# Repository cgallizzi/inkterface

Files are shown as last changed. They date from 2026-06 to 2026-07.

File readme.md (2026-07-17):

inkterface now playing

# Inkterface: Now Playing Edition

An e-ink faceplate for your Steam Machine that shows the box art, playtime,
and achievement progress of whatever you're playing — plus all the original
system telemetry readouts.

Video Project 2

> This is a community fork of
> [Valve's Inkterface](https://gitlab.steamos.cloud/SteamHardware/SteamMachine/inkterface),
> created by NaKyle Wright at Valve and released under the MIT license.
> All of the hardware design, assembly docs, and the original firmware and
> companion app are their work — this fork adds the artwork/"now playing"
> features and easier install tooling on top. Thank you Valve for open
> sourcing it!

## What this fork adds

* **Now Playing artwork mode**: when you launch a game, the panel switches to
  that game's box art with your total playtime and achievement progress
  rendered next to it (dithered for the e-ink look). When you quit, it goes
  back to the regular telemetry layout. Toggle it with the `Box Art` button
  in the configure screen.
* **Game collectors**: `Game Time` and `Achievements` readouts you can put in
  any panel field, alongside the stock CPU/GPU/fan stats.
* **Browser firmware flasher**: flash your Feather from Chrome/Edge at the
  project's GitHub Pages site — no toolchain install needed.
* **One-line app install**: paste a single command on your Steam Machine and
  you're done — no building, no USB sticks.

Achievement data comes from the Steam Community profile endpoint and requires
no API key, but your profile's game details need to be public for it to show.

## Quick Install (this fork)

**Firmware** — plug the Feather into any PC over USB and open the
[web flasher](https://cgallizzi.github.io/inkterface/) in Chrome or Edge, then
click Install for your board.

**App** — on the Steam Machine, open a terminal in desktop mode and run:

```sh
curl -fsSL https://raw.githubusercontent.com/cgallizzi/inkterface/main/scripts/install.sh | sh
```

That downloads the latest release to `~/Applications`, launches it, and from
there you pick your panel and click Install (bottom right) to set up the
background service. Prebuilt AppImages are also on the
[releases page](https://github.com/cgallizzi/inkterface/releases) if you'd rather
grab one manually.

Everything below is the original upstream documentation for building the
hardware and working from source.

## Required Hardware

* 1 x Adafruit ESP32-S3 Feather w/ 2MB PSRAM
    * [Link to V1 Board, as shown in the assembly video and document!](https://www.adafruit.com/product/5477)
    * [Link to V2 Board, accidentally the only link previously!](https://www.adafruit.com/product/5400)
    * Both the V1 and V2 modules work, but they have different pinouts, make sure
      to check if you see the "V2" silkscreen on your board and choose the correct
      pinout sheet and environment when building the firmware!
* 1 x [Adafruit eInk Breakout Friend](https://www.adafruit.com/product/4224)
* 1 x [Adafruit 5.83" Monochrome eInk Panel](https://www.adafruit.com/product/6397)
* 1 x [LP803860 Battery](https://www.adafruit.com/product/2011)
* 13 x M2.5 x 5mm Pan Head Machine Screws
    * [McMaster](https://www.mcmaster.com/92000A103/)
    * [Amazon](https://www.amazon.com/dp/B0GC58C2V5)
* 4 x [1/4" x 1/4" x 3/16" Stepped Magnet SB443-OUT](https://www.kjmagnetics.com/sb443-out-neodymium-stepped-block-magnet)

## Assembly

Check out the assembly tutorial video in
[the upstream repo](https://gitlab.steamos.cloud/SteamHardware/SteamMachine/inkterface/-/blob/main/docs/Inkterface%20Assembly.mp4)
(kept out of this fork because it exceeds GitHub's file size limit),
or if you'd prefer there is a PDF version too `./docs/Inkterface Assembly.pdf`.

**_Warning: The screws will thread themselves into the plastic, but be VERY gentle
as it is easy to strip the plastic away and you may need to re-print parts!_**

1. Print parts from `./cad` folder.
    * Individual parts are included as separate STEP files, but a combined file
      with all parts that is ready for printing on a Stratasys F370 build plate
      is also provided as `Inkterface - Print Plate.step`.
2. Attach the ESP32 Feather and eInk Breakout to the board plate layer using 4x screws.
    * Having them held in place helps with soldering the connections and sizing your wires.
3. Solder wires between the pins of the two boards.
    * MOSI/MISO/SCK/GND all connect directly as expected.
    * 3V3 from the feather connects to VIN on the breakout.
        * The 3V3 pin on the breakout is a 3V3 output.
    * For the **_V1_** feather connect these pins, like Feather -> Breakout:
        * PIN 6 -> ENA
        * PIN 9 -> BUSY
        * PIN 10 -> RST
        * PIN 11 -> SRCS
        * PIN 12 -> D/C
        * PIN 13 -> ECS
    * For the **_V2_** feather connect these pins, like Feather -> Breakout:
        * PIN 32 -> ENA
        * PIN 15 -> BUSY
        * PIN 33 -> RST
        * PIN 27 -> SRCS
        * PIN 12 -> D/C
        * PIN 13 -> ECS
    * **_NOTE:_** On both feather versions we connect to pins in the same physical
        positions, but they are different logical pins in the firmware.
4. Place the e-ink panel into the matching recess in the faceplate part.
5. Fit the two midplates in.
6. Place the 4 magnets into the recesses in each corner of of the midplates.
    * Magnetic field orientation doesn't matter, they connect to metal slugs
      in the Steam Machine chassis.
7. Place the board plate over the midplates, aligning the magnets and screw holes.
8. Fasten the boardplate with 8x screws in the screw holes along the edges.
9. Connect the e-ink panel to the breakout board.
    * Be careful when handling the flex that comes out of the panel, it is fragile
      and should not be bent or folded.
10. Place the battery in the recess, tucking its wire under the board plate and
    up into the clearance hole beside the feather.
11. Insert and fasten down the battery retainer/cover.
12. Plug the battery connecor into the feather.

Once you've assembled the unit it should be fairly solid and easily magnet to the
front of a Steam Machine!

You will need to build/flash the firmware onto the feather using the steps below.

## Usage

[Eventually we'll have an app up on Steam](https://store.steampowered.com/app/1222770)
but until then you can build an AppImage using the instructions further down in
this readme.

Once you have it built, take a look at `./docs/Inkterface Setup.pdf`, but the
basics are:
1. Enable bluetooth.
2. In desktop mode register as an app in Steam.
    * Or you can just run it directly.
3. Wait for it to discover your panel.
    * If it doesn't appear try clicking the reset button on the back and checking
      that bluetooth is enabled.
4. Select your panel, the name shown should match what's displayed on the inkterface.
    * They all start with an `INKTF-` prefix and then use a unique portion of the
      panels BLE MAC address.
5. On the configure screen, install the service using the button at the bottom
   right.
    * This will set itself up as a user service, so don't move the AppImage or
      that will break, no biggie though, you'll just need to re-run it.
    * Once the service is installed it might take 10-20 seconds for it to connect
      to the inkterface, that's fine, it just needs to go through discovery.
6. Finally you can click any of the readouts to adjust what they display.
    * We have several stats built in, but if you check out `include/panel-state.hpp`
      you can add any function that can return a `QString` or `double` and then
      `registerCollector()` to have it show up in the list.
      * There are some examples of stateful and idempotent collectors in `SysStats`,
        they get registered in the `PanelState` constructor.
7. Exit the configuration app.
    * The service is lightweight and runs in the background, you only need to
      run the config software to select a panel or to change what it displays.

## Building Interface

If you have Qt installed you should be able to open the cmake project in Qt Creator
and use that.

For better distributable builds you can setup a container for wider platform
support using the included `Containerfile`.

1. `podman build -t qt69-builder -f ./Containerfile`
2. `distrobox create --image qt69-builder --name qt69`
3. `distrobox enter qt69`
4. `./scripts/build.sh deploy`

That should produce an AppImage for you in the `./dist-linux-x86_64` folder.

This container uses an older version of Ubuntu and Qt 6.9 which should let us
build AppImages that will work on a wide range of modern systems.

## Building Firmware

For a mix of convenience and approachability this project uses
[PlatformIO](https://platformio.org), and in particular here you'll use the
[pio run](https://docs.platformio.org/en/latest/core/userguide/cmd_run.html)
command. Reading up on them can be useful, especial options like `--upload-port`
which could help if you have multiple serial ports.

If you're using the container from above you can just do:

1. `distrobox enter qt69`
2. `cd ./firmware`
3. If you have a **_V1_** feather: `pio run -e featherv1 -t upload`
4. If you have a **_V2_** feather: `pio run -e featherv2 -t upload`

And it should build and flash the firmware, if you want to get setup manually:

1. Install [PlatformIO](https://platformio.org) for your system.
2. `cd ./firmware`
3. If you have a **_V1_** feather: `pio run -e featherv1 -t upload`
4. If you have a **_V2_** feather: `pio run -e featherv2 -t upload`

Of course in both cases you need to have the ESP32 Feather attached via USB and
permission to interact with serial devices on your system.

**_NOTE:_** You can add build definitions and support for other boards by modifying
the `platformio.ini`, check it out to see the V1 and V2 feather environments.

## Design Docs

Planning out the UI and panel design is done in a Lunacy document you can find
in the `./design` folder.

Lunacy is an open source alternative to tools like Figma that can work entirely
offline.

## License

This project is licensed under the MIT License, see LICENSE.

This project depends on third-party software that is distributed under its own
licenses. Those licenses remain applicable to the respective components and
are not modified by this project's license.

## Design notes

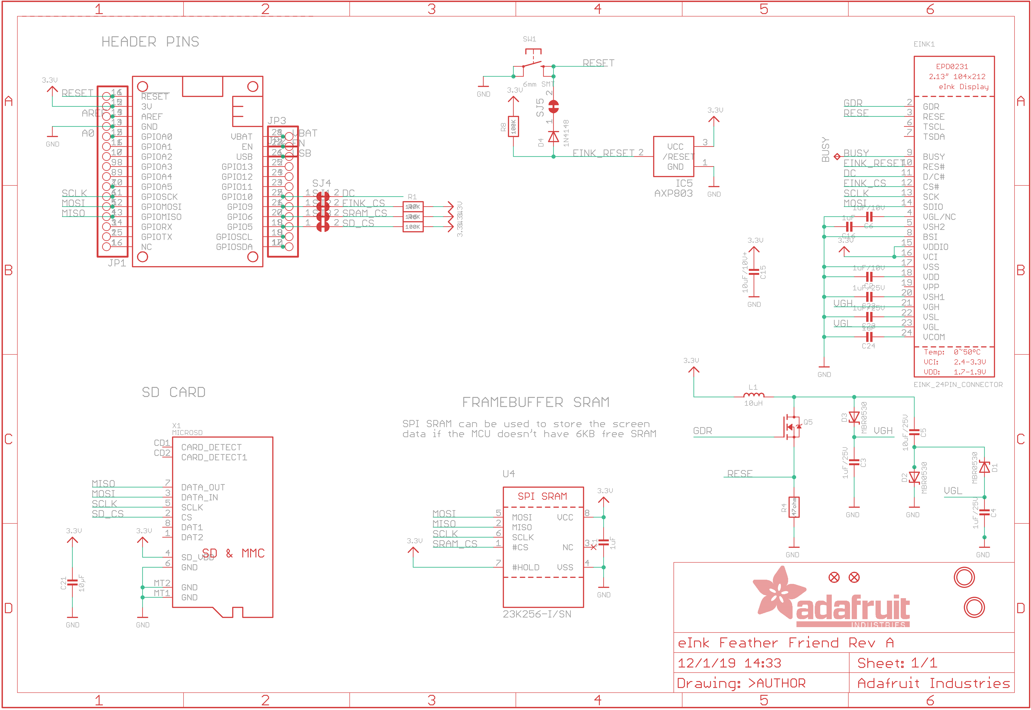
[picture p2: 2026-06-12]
docs/eInk Feather Friend Schematic.png

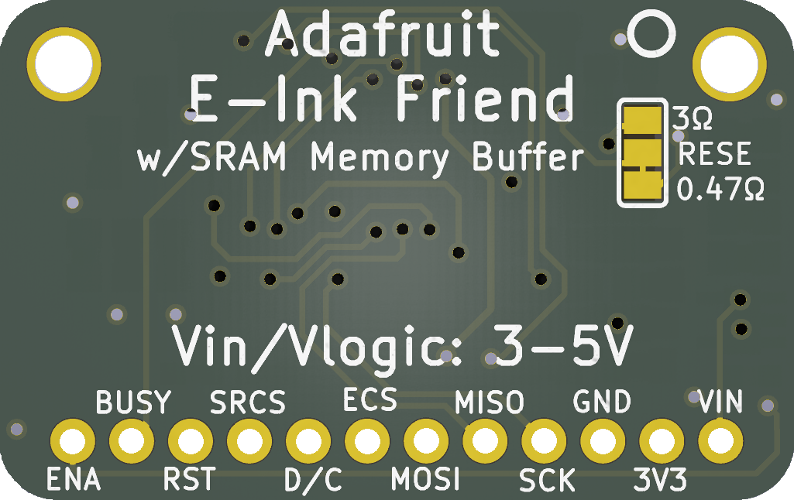
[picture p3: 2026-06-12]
design/breakout-board.png

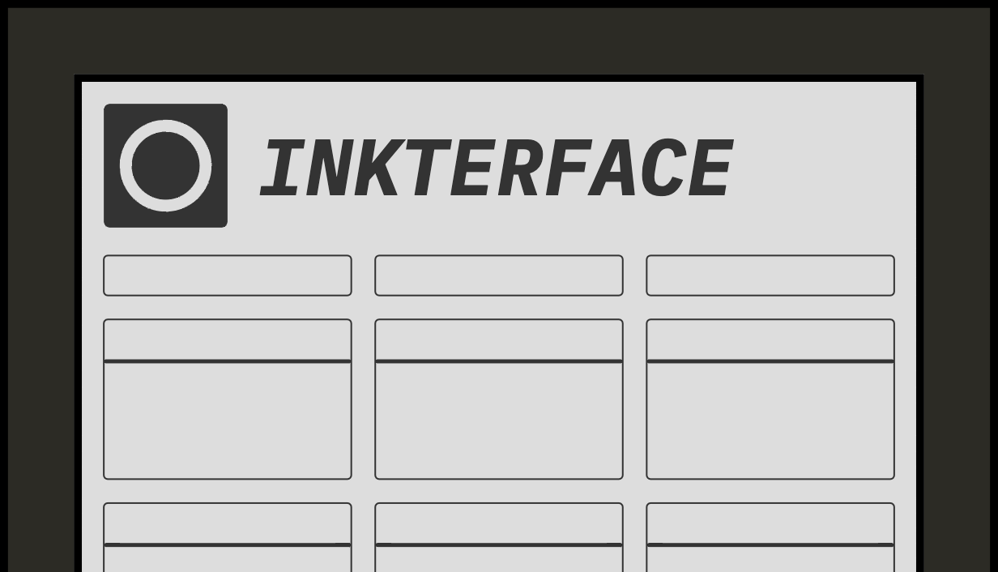
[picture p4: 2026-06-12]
design/store-assets/Main_Capsule.png

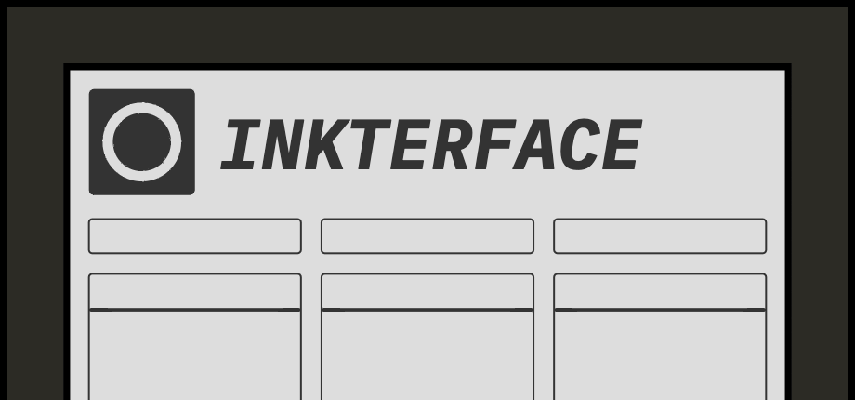
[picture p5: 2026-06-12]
design/store-assets/Library_Header.png

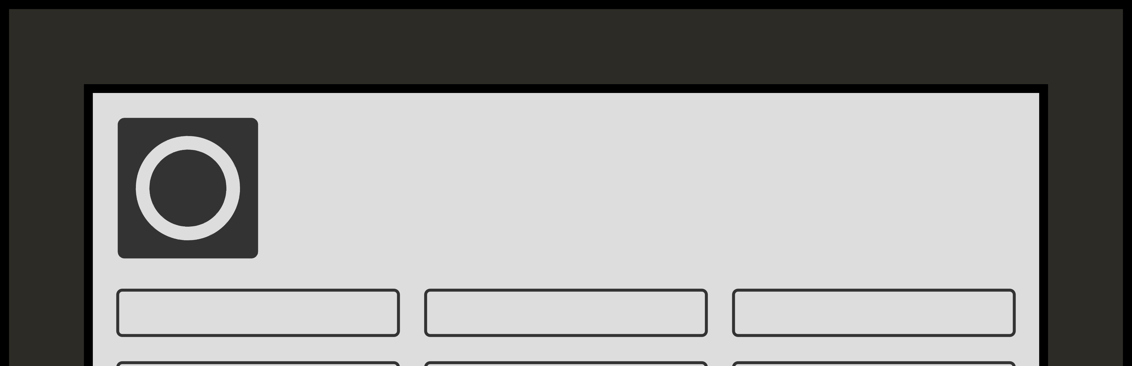
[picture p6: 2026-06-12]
design/store-assets/Library_Hero.png

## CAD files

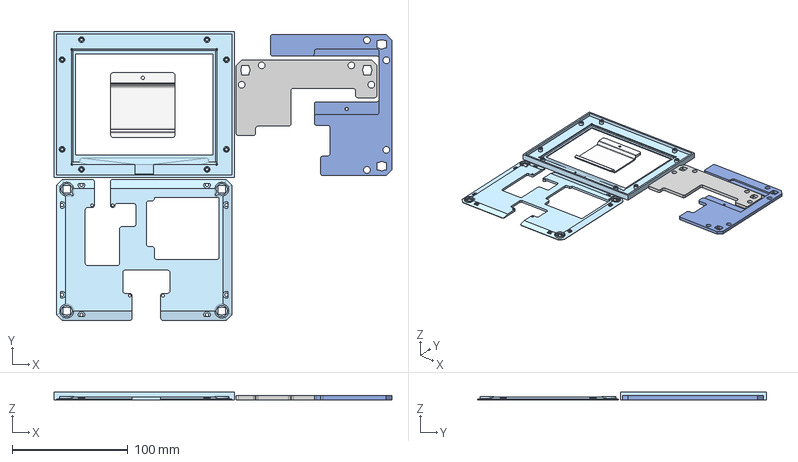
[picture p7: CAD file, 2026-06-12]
cad/Inkterface - Print Plate.step
292.1 x 249.6 x 6.50 mm
Faceplate
Battery Retainer
Board Plate
Midplate Left
Midplate Right

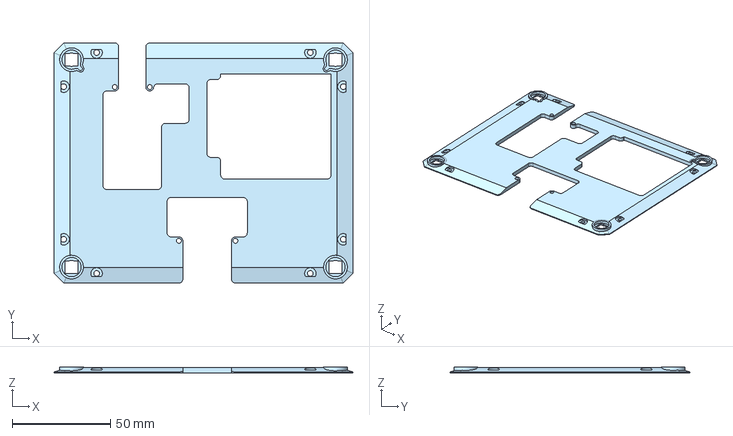
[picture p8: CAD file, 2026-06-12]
cad/Inkterface - Board Plate.step
151.8 x 121.9 x 2.81 mm

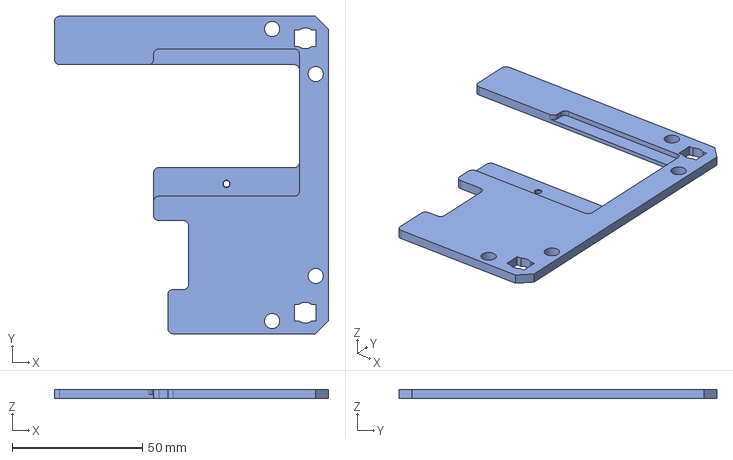
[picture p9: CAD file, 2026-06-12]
cad/Inkterface - Midplate Left.step
105.2 x 121.9 x 3.56 mm

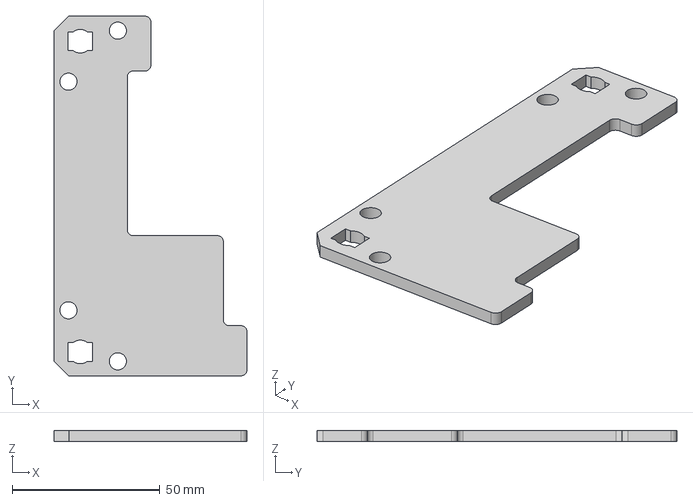
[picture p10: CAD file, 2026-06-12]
cad/Inkterface - Midplate Right.step
65.4 x 121.9 x 3.56 mm

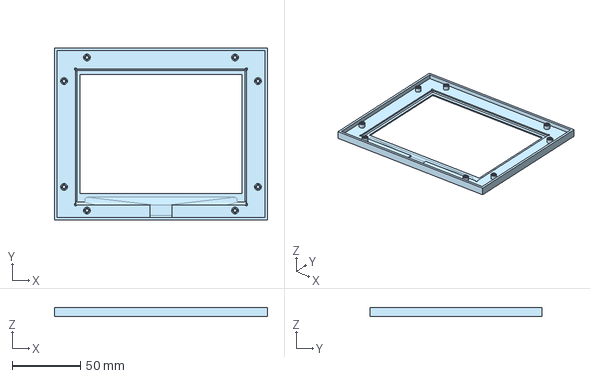
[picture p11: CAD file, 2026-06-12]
cad/Inkterface - Faceplate.step
156.0 x 126.1 x 6.50 mm

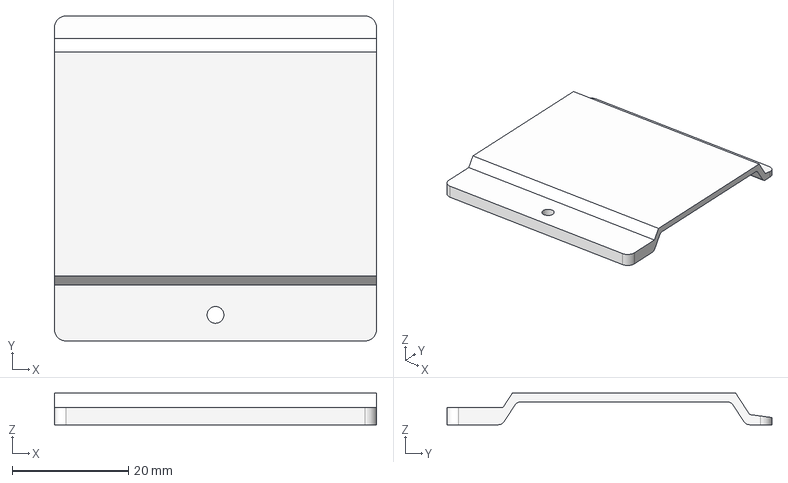
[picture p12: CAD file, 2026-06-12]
cad/Inkterface - Battery Retainer.step
55.5 x 56.0 x 5.44 mm

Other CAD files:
cad/Inkterface - Battery Retainer.stl
cad/Inkterface - Board Plate.stl
cad/Inkterface - Faceplate.stl
cad/Inkterface - Midplate Left.stl
cad/Inkterface - Midplate Right.stl
cad/Inkterface - Print Plate.stl

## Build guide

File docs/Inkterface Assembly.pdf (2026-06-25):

### Inkterface Assembly (p. 1/2)

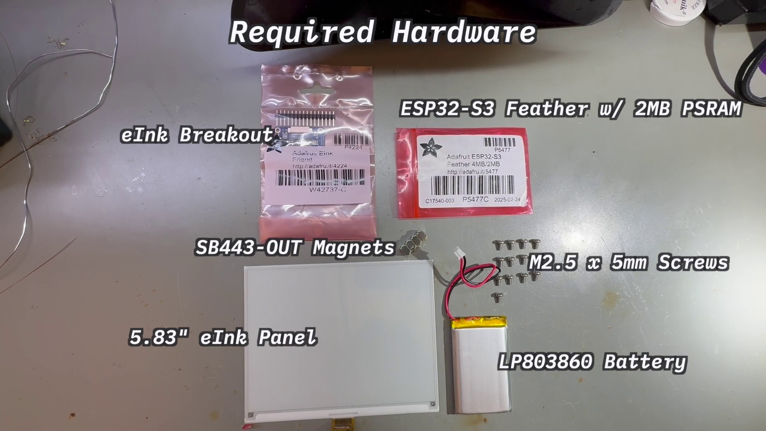
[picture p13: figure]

Collect hardware:
> 1x 5.83" eInk Panel
> 1x Adafruit eInk Breakout
> 1x ESP32-S3 Feather w/ 2MB PSRAM > 1x LP803860 Battery
> 4x K&J Magnetics SB443-OUT Magnets > 13x M2.6 x 5mm Machine Screws

See project readme for links.

Print plastic parts:
> 1x Faceplate
> 1x Battery Retainer
> 1x Right Midplate
> 1x Left Midplate
> 1x Board Plate

There are STEP and STL files provided in the CAD folder of the project.

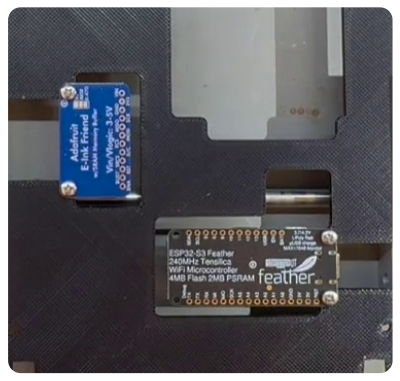
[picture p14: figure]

Attach boards to board plate:

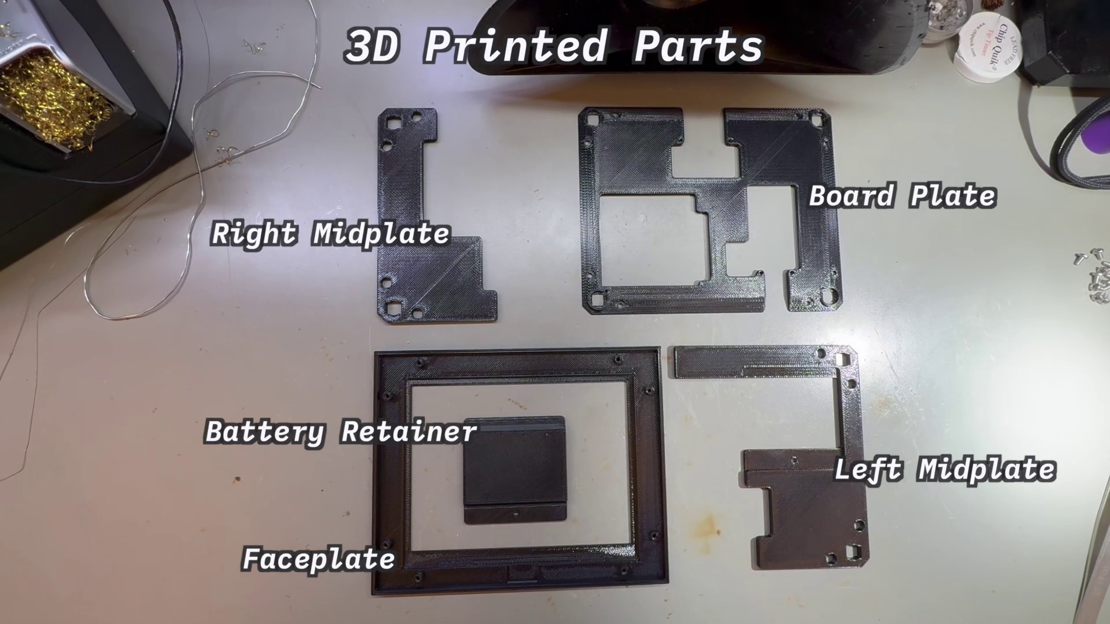
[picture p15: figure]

Use 4 M2.5 x 5mm screws, the breakout and feather.

The boards should lay on the flat side, with the connectors and components facing down.

Mounting them like this makes wiring and soldering easier. Tighten screws gently to avoid damaging the plastic!

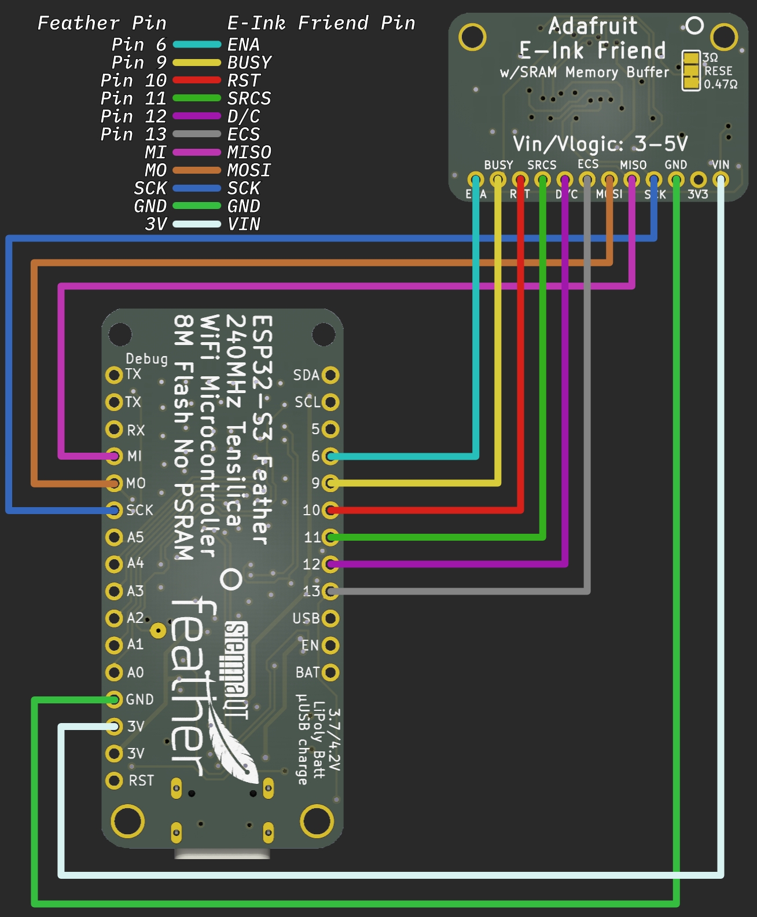
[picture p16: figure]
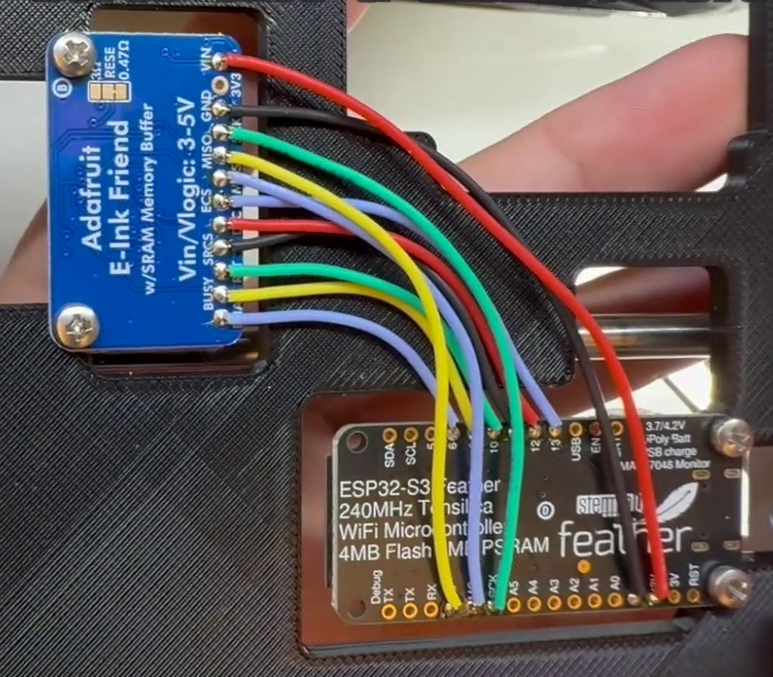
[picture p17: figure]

Wire boards together:
Solder fine gauge wire connections between the boards according to the wiring diagram.

I prefer ~30AWG stranded wire with silicone insulation, but just try to keep the wires as short and direct as possible.

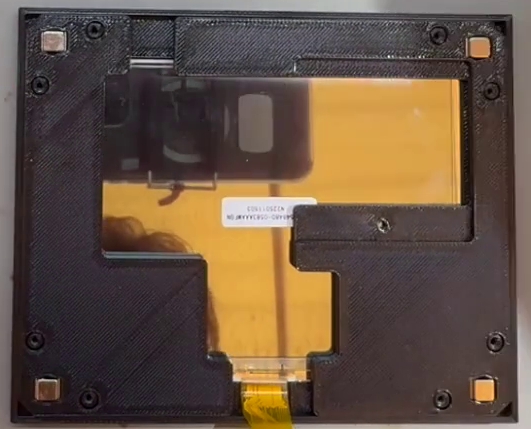
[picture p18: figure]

Assemble faceplate and midplates:
Remove protective film from eInk panel. Place panel in matching recess in faceplate. Place midplates down as seen in image. Install 4 K&J SB443-OUT magnets.
1 in each corner, you may need to press them in forcefully depending on your printer.
p. 1/2

### Inkterface Assembly (p. 2/2)

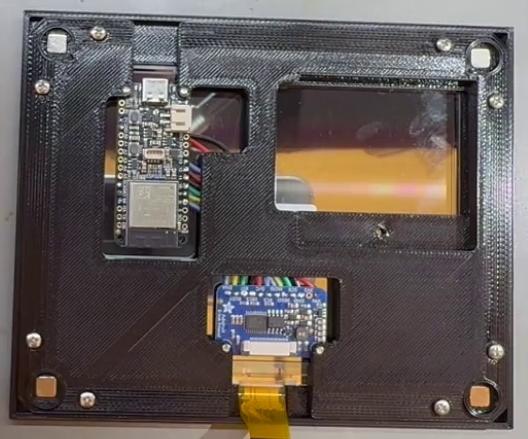
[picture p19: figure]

Mount board plate over midplates:
Carefully position wires so that they fit into the channel between the midplates.

Use 8 M2.5 x 5mm screws, gently tightened to avoid damaging the plastic.

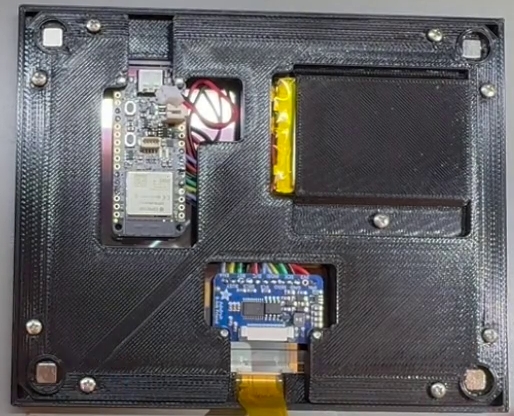
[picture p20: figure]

Mount battery and battery retainer:
Feed battery cable under board plate and up next to the battery connector on the feather.

Place the battery retainer over the battery and fix it in place with 1 M2.5 x 5mm screw.

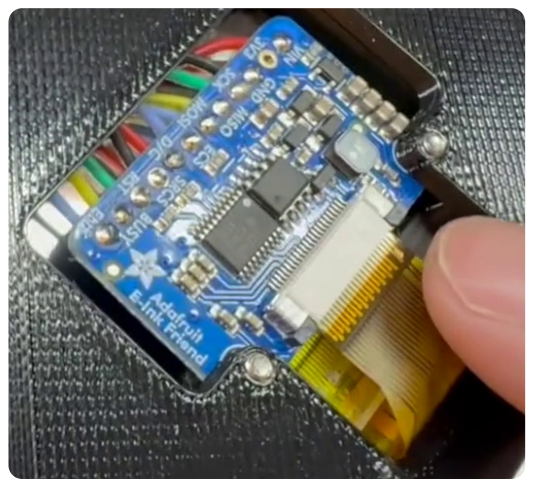
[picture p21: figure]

Connect flex cable to breakout:
Carefully unlatch the connector and feed the flex cable into it.

The cable should seat as shown in the image.

Carefully latch the connector.

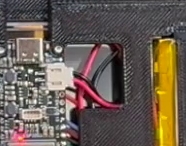
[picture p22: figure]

Connect the battery to the feather:
Connect the battery to the feather.

You should see a red light, this indicates that the board has power.

Assembly Complete!
The next step is to flash the firmware, please see the readme for instructions on setup, building, and flashing!
p. 2/2

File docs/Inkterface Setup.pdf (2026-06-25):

### Inkterface Setup

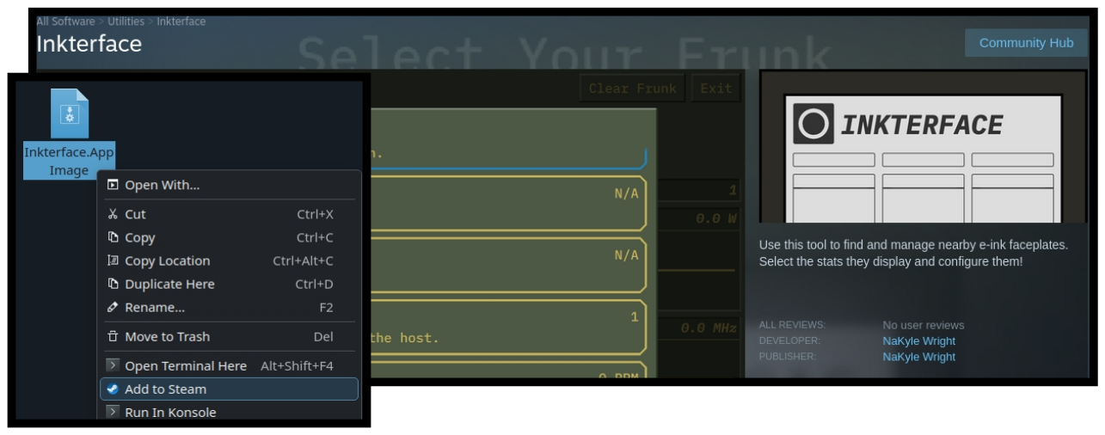
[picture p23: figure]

Install Application:
You can add the AppImage to Steam or install it once it's available on the store!

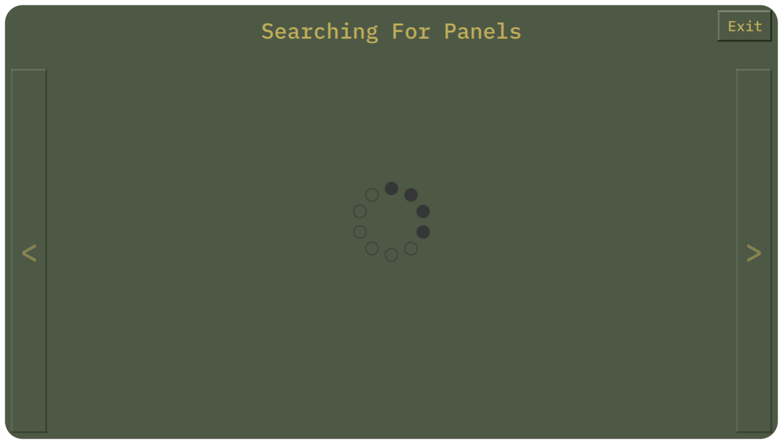
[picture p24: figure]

Discover Nearby Panels:
Make sure you have bluetooth enabled and that the panel is nearby.

If it doesn't appear try pressing the reset button on the back.

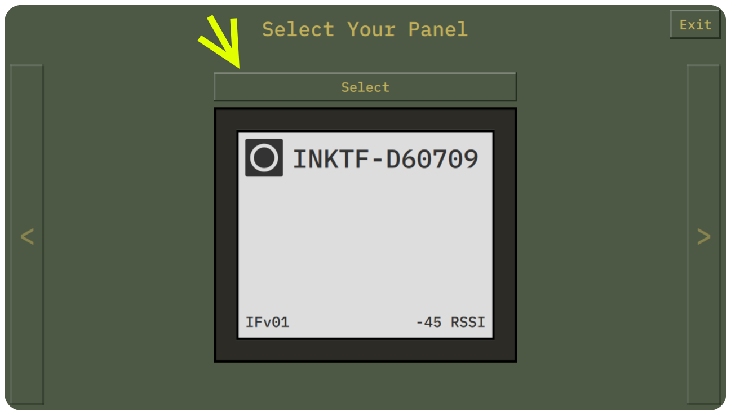
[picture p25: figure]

Select Your Panel:
Panels will show up on this as a list, sorted by RSSI, and with unsupported inkterfaceversions at the back.

Compare the name on your panel to the name shown on the result, then click Select.

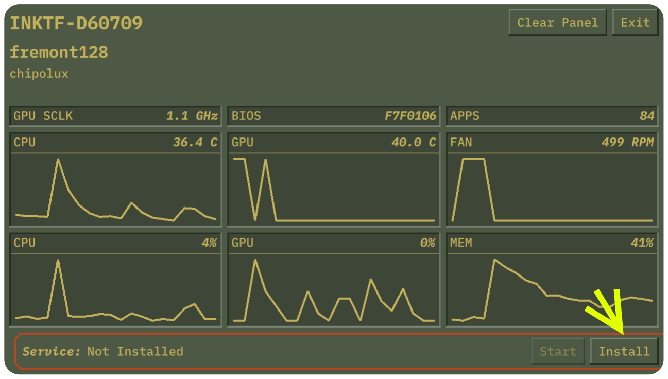
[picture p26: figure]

Install Service:
Once a panel is selected you will be taken to the configuration page.

Install the service that will run in the background to collect stats and transmit them to the Inkterface.

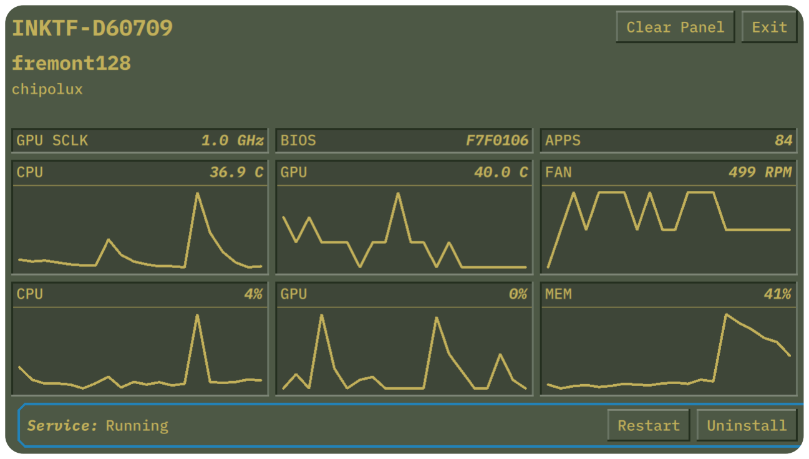
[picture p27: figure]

Configure What Inkterface Shows:
By clicking on any of the readouts you can adjust what is shown.

Changes take place on the next update cycle.

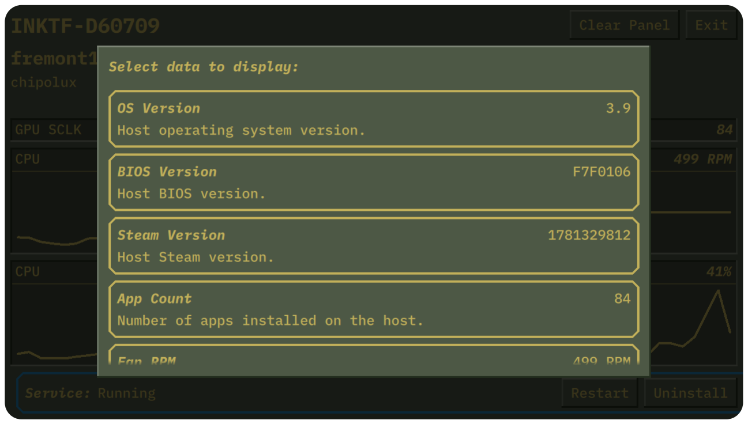
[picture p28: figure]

You're done! You can close the app, the service will maintain the connection automatically.

If you have issues try re-installing Inkterface, re-installing the service, and resetting your Inkterface!

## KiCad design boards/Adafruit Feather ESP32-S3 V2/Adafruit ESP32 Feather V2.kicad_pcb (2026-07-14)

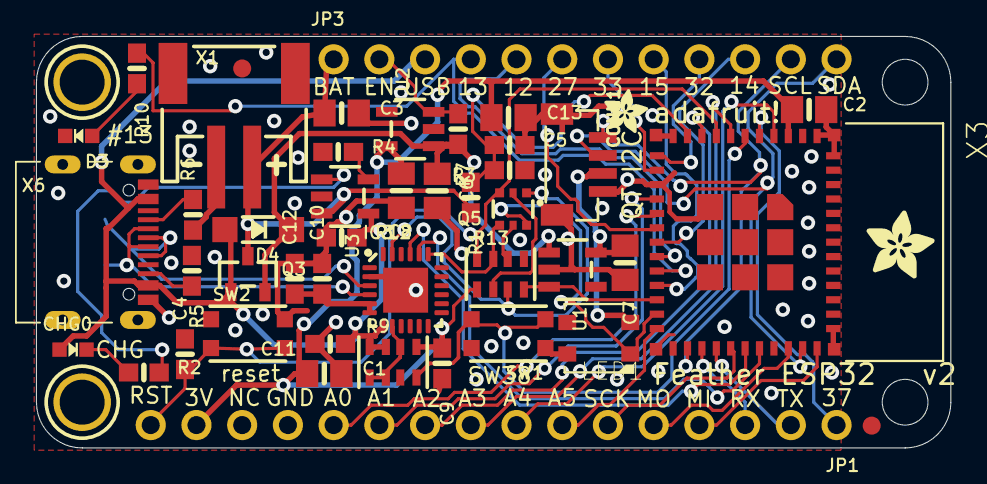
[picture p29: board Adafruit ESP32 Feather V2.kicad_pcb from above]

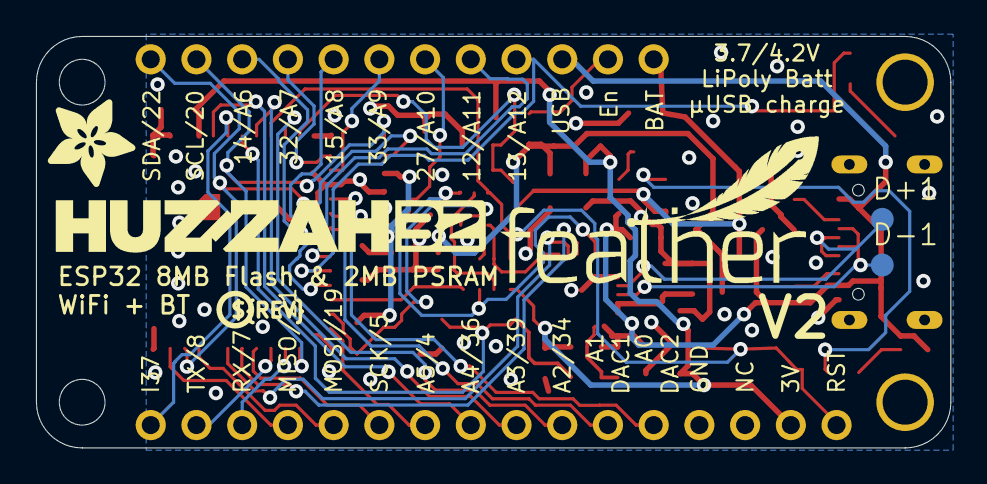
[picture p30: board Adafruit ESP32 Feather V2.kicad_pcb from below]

Board: 2 copper layers, 50.8 x 22.9 mm, 56 parts (6 on the bottom side), 49 nets.

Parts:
C1, C2, C13: 10uF; 0805-NO
C3, C6, C7, C8: 10µF; 0805-NO
C4, C5, C9, C10: 1uF; 0603-NO
C11, C12: 0.1uF; 0603-NO
CHG0: ORANGE; CHIPLED_0603_NOOUTLINE
CONN1: STEMMA_I2C_QTRA; JST_SH4_RA
D3: RED; CHIPLED_0603_NOOUTLINE
D4: MBR540; SOD-123
D+1: TPB1,27; B1,27_385
D-1: TPB1,27; B1,27_385
IC3: CP2102N-24; QFN24_4MM_SMSC
JP1: 1X16_ROUND
JP3: 1X12_ROUND
LED1: WS2812B3535; LED3535
Q3: DMG3415U; SOT23-R
Q5: DUAL NPN; SOT363
R1, R3: 200K; 0603-NO
R2, R4, R5, R6, R10: 5.1K; 0603-NO
R7, R12: 100K; 0603-NO
R9: 47K; RESPACK_4X0603
R13: 10K; RESPACK_4X0603
SW1, SW2: KMR2; BTN_KMR2_4.6X2.8
U1, U2: AP2112-3.3; SOT23-5
U3: MCP73831T-2ACI/OT; SOT23-5
U$7: ADAFRUIT_5MM
U$9: FEATHERLOGO_MED
U$13: PCBFEAT-REV-040
U$14: ADAFRUIT_2.5MM
U$15: ADAFRUIT_3.5MM
U$31, U$32: MOUNTINGHOLE2.5; MOUNTINGHOLE_2.5_PLATED
U$34, U$35: FIDUCIAL_1MM
U$43: HUZZAH32
UNK_HOLE_0: dummyfp0
UNK_HOLE_1: dummyfp1
X1: JSTPH; JSTPH2_BATT
X3: ESP32-PICO-MINI-02MINI; ESP32-PICO-MINI
X6: USB Type C; USB_C_CUSB31-CFM2AX-01-X

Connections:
3.3V: C1.1, C2.1, C8.1, C9.1, C13.1, JP1.15, R9.5, R13.1, U2.5, X3.3
3.45V: C10.1, C12.1, IC3.5, IC3.6
A0_DAC2: JP1.12, X3.16
A1_DAC1: JP1.11, X3.15
A2_I34: JP1.10, X3.9
A3_I39: JP1.9, X3.7
A4_I36: JP1.8, X3.4
A5_IO4: JP1.7, X3.24
A13_I35: C5.1, R1.1, R3.2, X3.10
CC1: R6.2, X6.A5
CC2: R5.2, X6.B5
D+: D+1.TP, IC3.3, X6.A6, X6.B6
D-: D-1.TP, IC3.4, X6.A7, X6.B7
DTR: IC3.23, Q5.1, R13.3
EN: JP3.2, R7.1, U2.3
GND: C1.2, C2.2, C3.2, C4.2, C5.2, C6.2, C7.2, C8.2, C9.2, C10.2, C11.2, C12.2, C13.2, CONN1.1, CONN1.MT1, CONN1.MT2, D3.C, IC3.2, IC3.THERM, JP1.13, LED1.4, R3.1, R4.1, R5.1, R6.1, R9.3, R12.1, R13.5, SW1.A, SW1.A', SW2.A, SW2.A', U1.2, U2.2, U3.2, X1.1, X1.NC1, X1.NC2, X3.1, X3.2, X3.11, X3.14, X3.36, X3.37, X3.38, X3.39, X3.40, X3.41, X3.42, X3.43, X3.44, X3.45, X3.46, X3.47, X3.48, X3.49, X3.50, X3.51, X3.52, X3.53, X3.54, X3.55, X3.56, X3.57, X3.58, X3.59, X3.60, X3.61, X6.A1B12, X6.B1A12
GPIO0: LED1.1, Q5.6, X3.23
I37: JP1.1, X3.5
IO12_A11: JP3.5, X3.19
IO13_A12: JP3.4, R10.1, X3.20
IO14_A6: JP3.10, X3.18
IO15_A8: JP3.8, X3.21
IO27_A10: JP3.6, X3.17
IO32_A7: JP3.9, X3.12
IO33_A9: JP3.7, X3.13
MISO: JP1.4, X3.35
MOSI: JP1.5, X3.33
unnamed: CHG0.C, R2.1
unnamed: R2.2, U3.1
unnamed: R4.2, U3.5
unnamed: D3.A, R10.2
unnamed: R9.4, SW1.B, SW1.B', X3.6
unnamed: Q5.5, R13.6
unnamed: Q5.2, R13.2
NEOI2C_PWR: R13.4, U1.3, X3.22
RTS: IC3.19, Q5.4, R13.7
RX/IO7: JP1.3, X3.27
RXD0: IC3.21, X3.30
SCK: JP1.6, X3.29
SCL: CONN1.4, JP3.11, X3.26
SDA: CONN1.3, JP3.12, X3.34
TX/IO8: JP1.2, X3.28
TXD0: IC3.20, X3.31
VBAT: C3.1, JP3.1, Q3.3, R1.2, U3.3, X1.2
VBUS: C11.1, CHG0.A, D4.A, IC3.7, JP3.3, Q3.1, R9.7, R9.8, R12.2, U3.4, X6.A4B9, X6.B4A9
VBUS_DET: IC3.8, R9.1, R9.2, R9.6
VHI: C6.1, D4.C, Q3.2, R7.2, U1.1, U2.1
V_NEOI2C: C7.1, CONN1.2, LED1.2, U1.5
~RESET: C4.1, JP1.16, Q5.3, R13.8, SW2.B, SW2.B', X3.8

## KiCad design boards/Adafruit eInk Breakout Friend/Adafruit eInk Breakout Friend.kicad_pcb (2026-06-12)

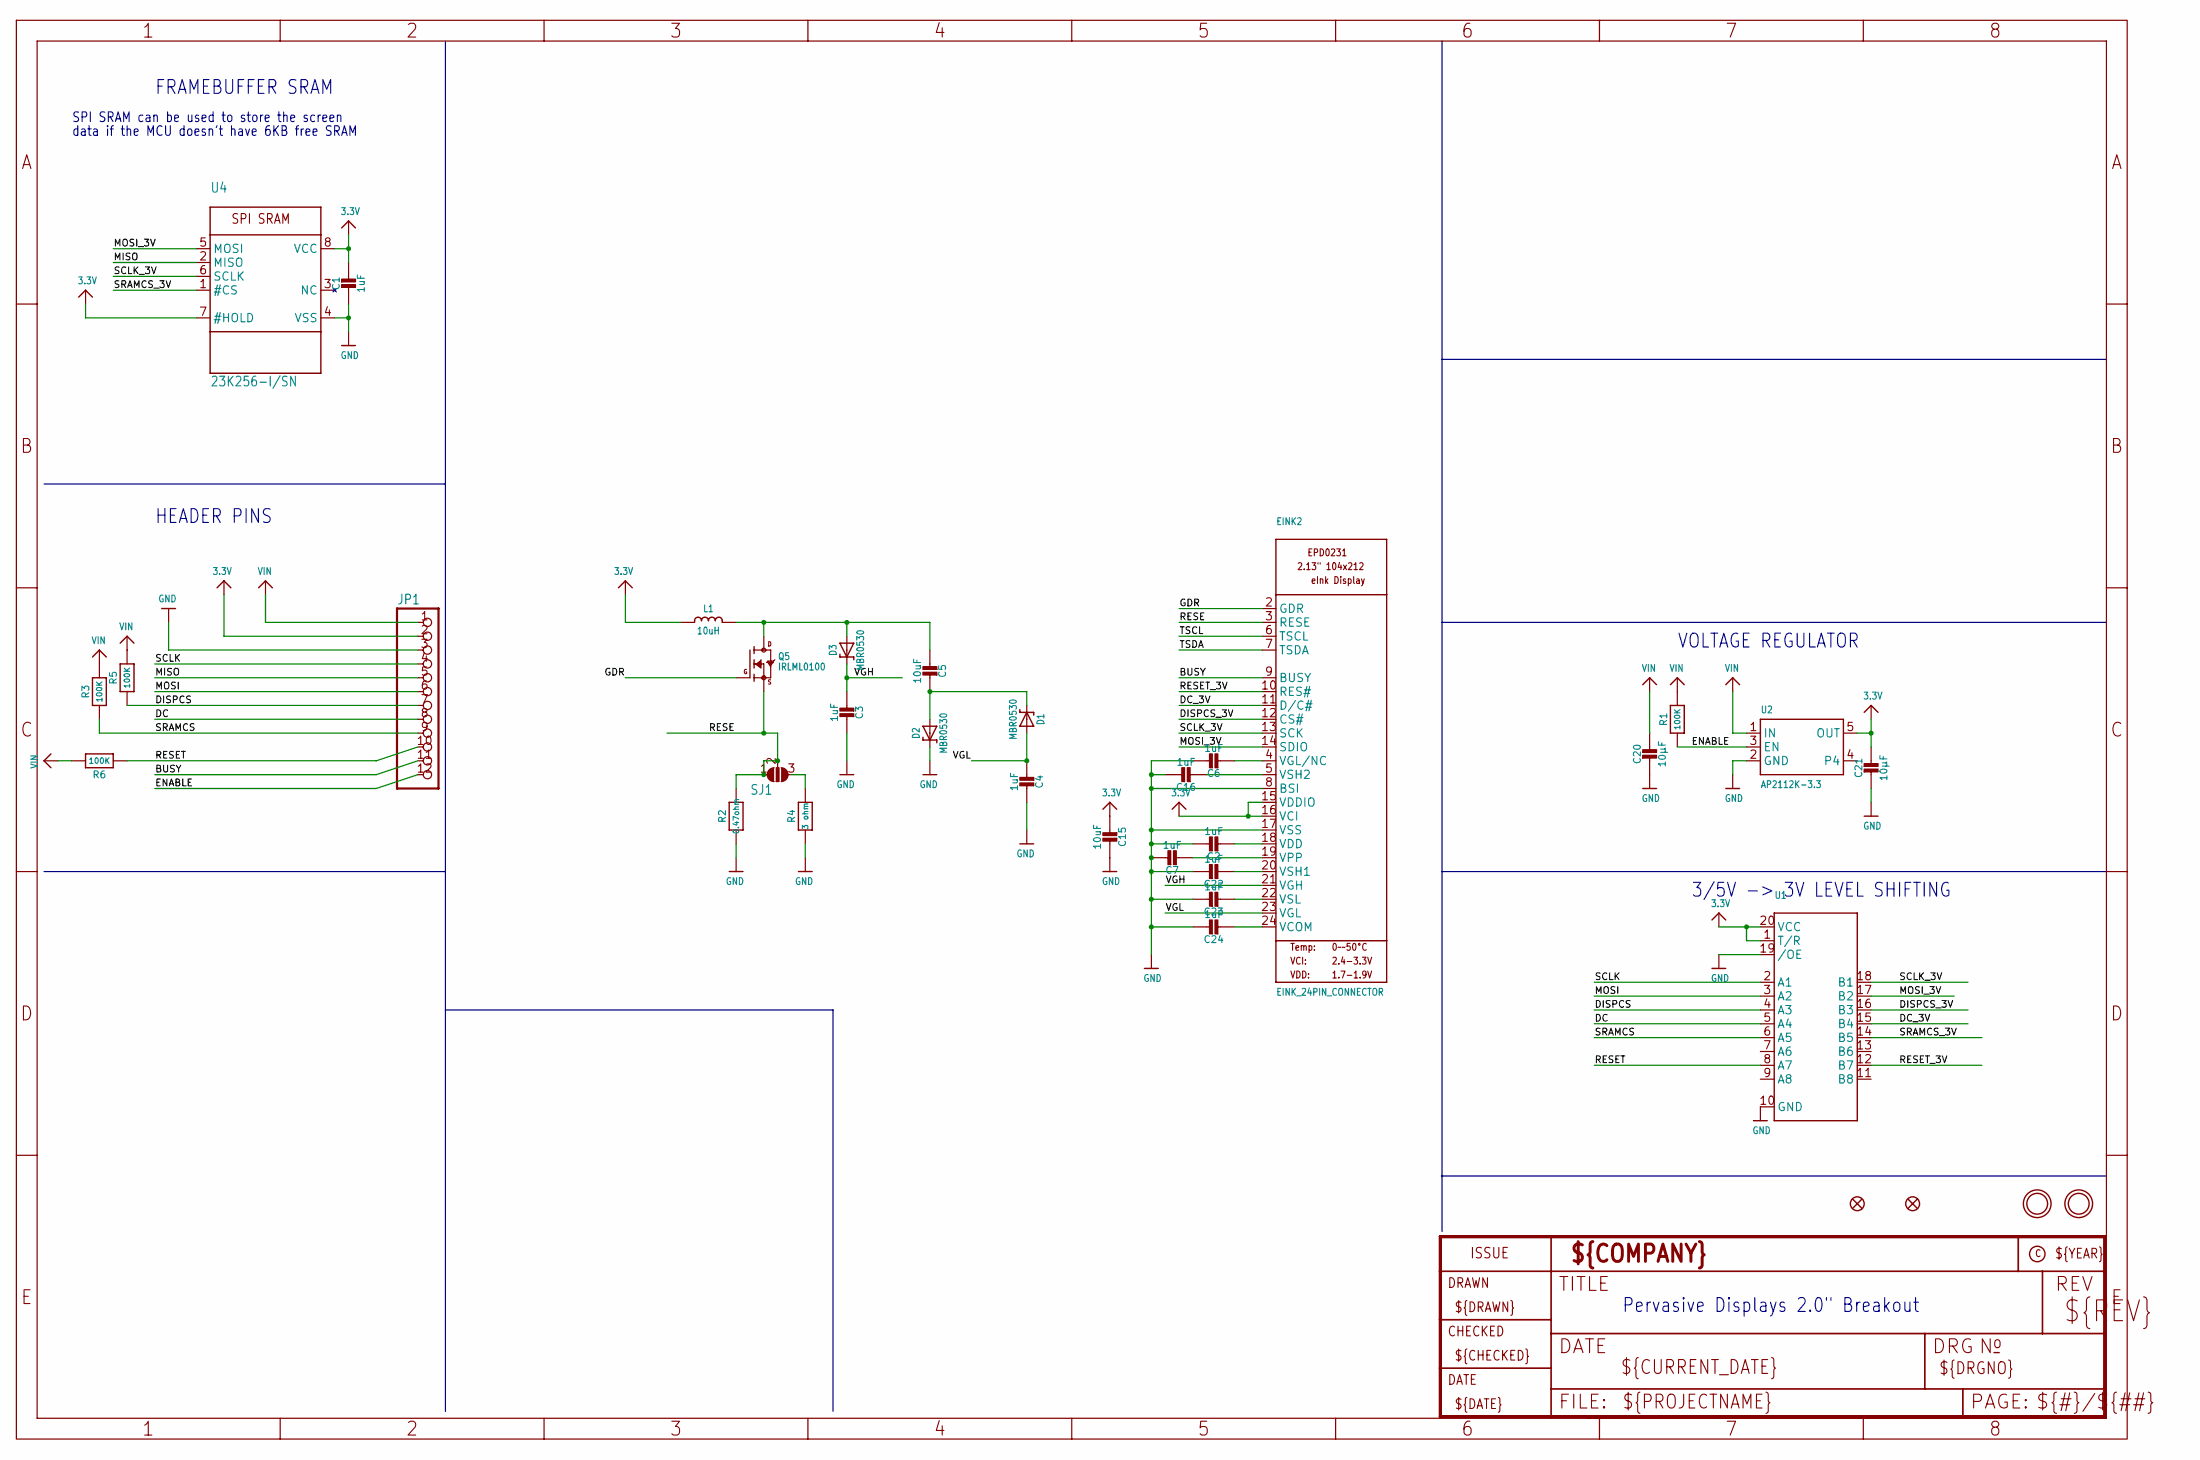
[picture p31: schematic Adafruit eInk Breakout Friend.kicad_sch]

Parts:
C1: 1uF; 0805_10MGAP
C2, C3, C4, C6, C7, C16, C22, C23, C24: 1uF; 0805-NO
C5, C15: 10uF; 0805-NO
C20, C21: 10µF; 0805-NO
D1, D2, D3: MBR0530; SOD-123
EINK2: EINK_24PIN_CONNECTOR; EINK_24PIN
FID2, FID3: FIDUCIAL_1MM
JP1: HEADER-1X1276MIL; 1X12_ROUND_76MIL
L1: 10uH; INDUCTOR_4X4MM_NR401
Q5: IRLML0100; SOT23-3
R1, R3, R5, R6: 100K; 0603-NO
R2: 0.47ohm; 0805-NO
R4: 3 ohm; 0805-NO
SJ1: SOLDERJUMPER_2WAY; SOLDERJUMPER_2WAY_OPEN_NOPASTE
U1: 74LCX245; TSSOP20
U2: AP2112K-3.3; SOT23-5
U4: 23K256-I/SN; SOIC8_150MIL
U$3, U$4: MOUNTINGHOLE2.5; MOUNTINGHOLE_2.5_PLATED

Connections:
3.3V: C1.1, C15.2, C21.1, EINK2.15 (VDDIO), EINK2.16 (VCI), JP1.2, L1.P$2 (2), U1.1 (T/R), U1.20 (VCC), U2.5 (OUT), U4.7 (#HOLD), U4.8 (VCC)
BUSY: EINK2.9 (BUSY), JP1.11
DC: JP1.8, U1.5 (A4)
DC_3V: EINK2.11 (D/C#), U1.15 (B4)
DISPCS: JP1.7, R5.1, U1.4 (A3)
DISPCS_3V: EINK2.12 (CS#), U1.16 (B3)
ENABLE: JP1.12, R1.1, U2.3 (EN)
GDR: EINK2.2 (GDR), Q5.1 (G)
GND: C1.2, C2.1, C3.2, C4.2, C6.1, C7.1, C15.1, C16.1, C20.2, C21.2, C22.1, C23.1, C24.1, D2.C, EINK2.8 (BSI), EINK2.17 (VSS), JP1.3, R2.2, R4.2, U1.10 (GND), U1.19 (/OE), U2.2 (GND), U4.4 (VSS)
MISO: JP1.5, U4.2 (MISO)
MOSI: JP1.6, U1.3 (A2)
MOSI_3V: EINK2.14 (SDIO), U1.17 (B2), U4.5 (MOSI)
unnamed: C7.2, EINK2.19 (VPP)
unnamed: C5.2, D1.C, D2.A
unnamed: C5.1, D3.A, L1.P$1 (1), Q5.3 (D)
unnamed: C16.2, EINK2.5 (VSH2)
unnamed: C2.2, EINK2.18 (VDD)
unnamed: C22.2, EINK2.20 (VSH1)
unnamed: R4.1, SJ1.3
unnamed: C6.2, EINK2.4 (VGL/NC)
unnamed: C23.2, EINK2.22 (VSL)
unnamed: C24.2, EINK2.24 (VCOM)
RESE: EINK2.3 (RESE), Q5.2 (S), R2.1, SJ1.1, SJ1.2
RESET: JP1.10, R6.1, U1.8 (A7)
RESET_3V: EINK2.10 (RES#), U1.12 (B7)
SCLK: JP1.4, U1.2 (A1)
SCLK_3V: EINK2.13 (SCK), U1.18 (B1), U4.6 (SCLK)
SRAMCS: JP1.9, R3.1, U1.6 (A5)
SRAMCS_3V: U1.14 (B5), U4.1 (#CS)
TSCL: EINK2.6 (TSCL)
TSDA: EINK2.7 (TSDA)
VGH: C3.1, D3.C, EINK2.21 (VGH)
VGL: C4.1, D1.A, EINK2.23 (VGL)
VIN: C20.1, JP1.1, R1.2, R3.2, R5.2, R6.2, U2.1 (IN)

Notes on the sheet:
3/5V -> 3V LEVEL SHIFTING
SPI SRAM can be used to store the screen
data if the MCU doesn't have 6KB free SRAM
Pervasive Displays 2.0" Breakout
VOLTAGE REGULATOR
FRAMEBUFFER SRAM
HEADER PINS

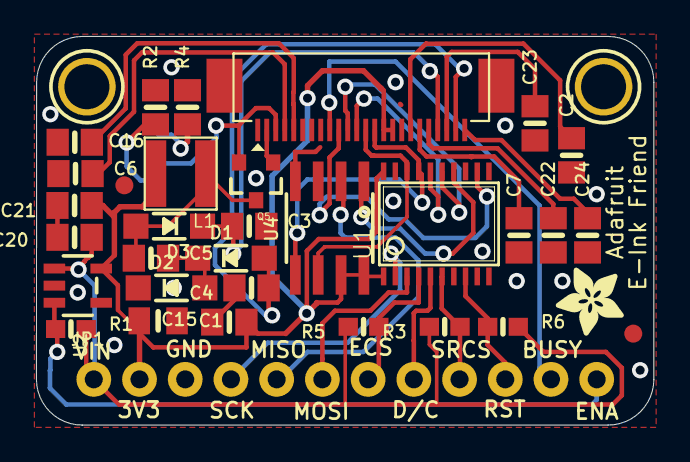
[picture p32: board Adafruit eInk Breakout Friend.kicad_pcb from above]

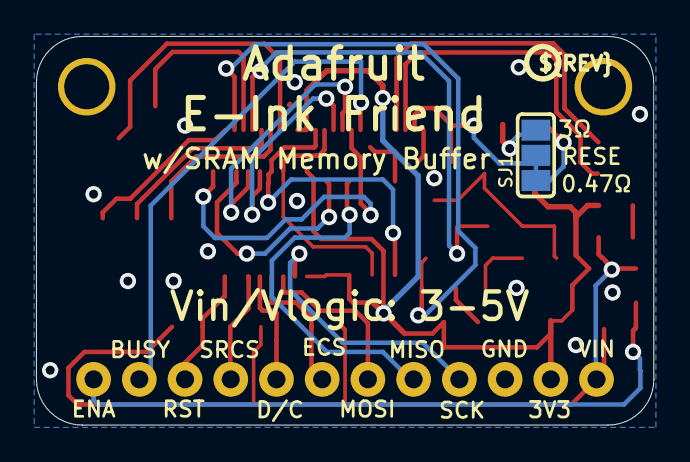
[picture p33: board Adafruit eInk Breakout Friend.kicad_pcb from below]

Board: 2 copper layers, 34.3 x 21.6 mm, 37 parts (2 on the bottom side), 32 nets.

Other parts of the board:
U$2: ADAFRUIT_3.5MM
U$9: PCBFEAT-REV-040

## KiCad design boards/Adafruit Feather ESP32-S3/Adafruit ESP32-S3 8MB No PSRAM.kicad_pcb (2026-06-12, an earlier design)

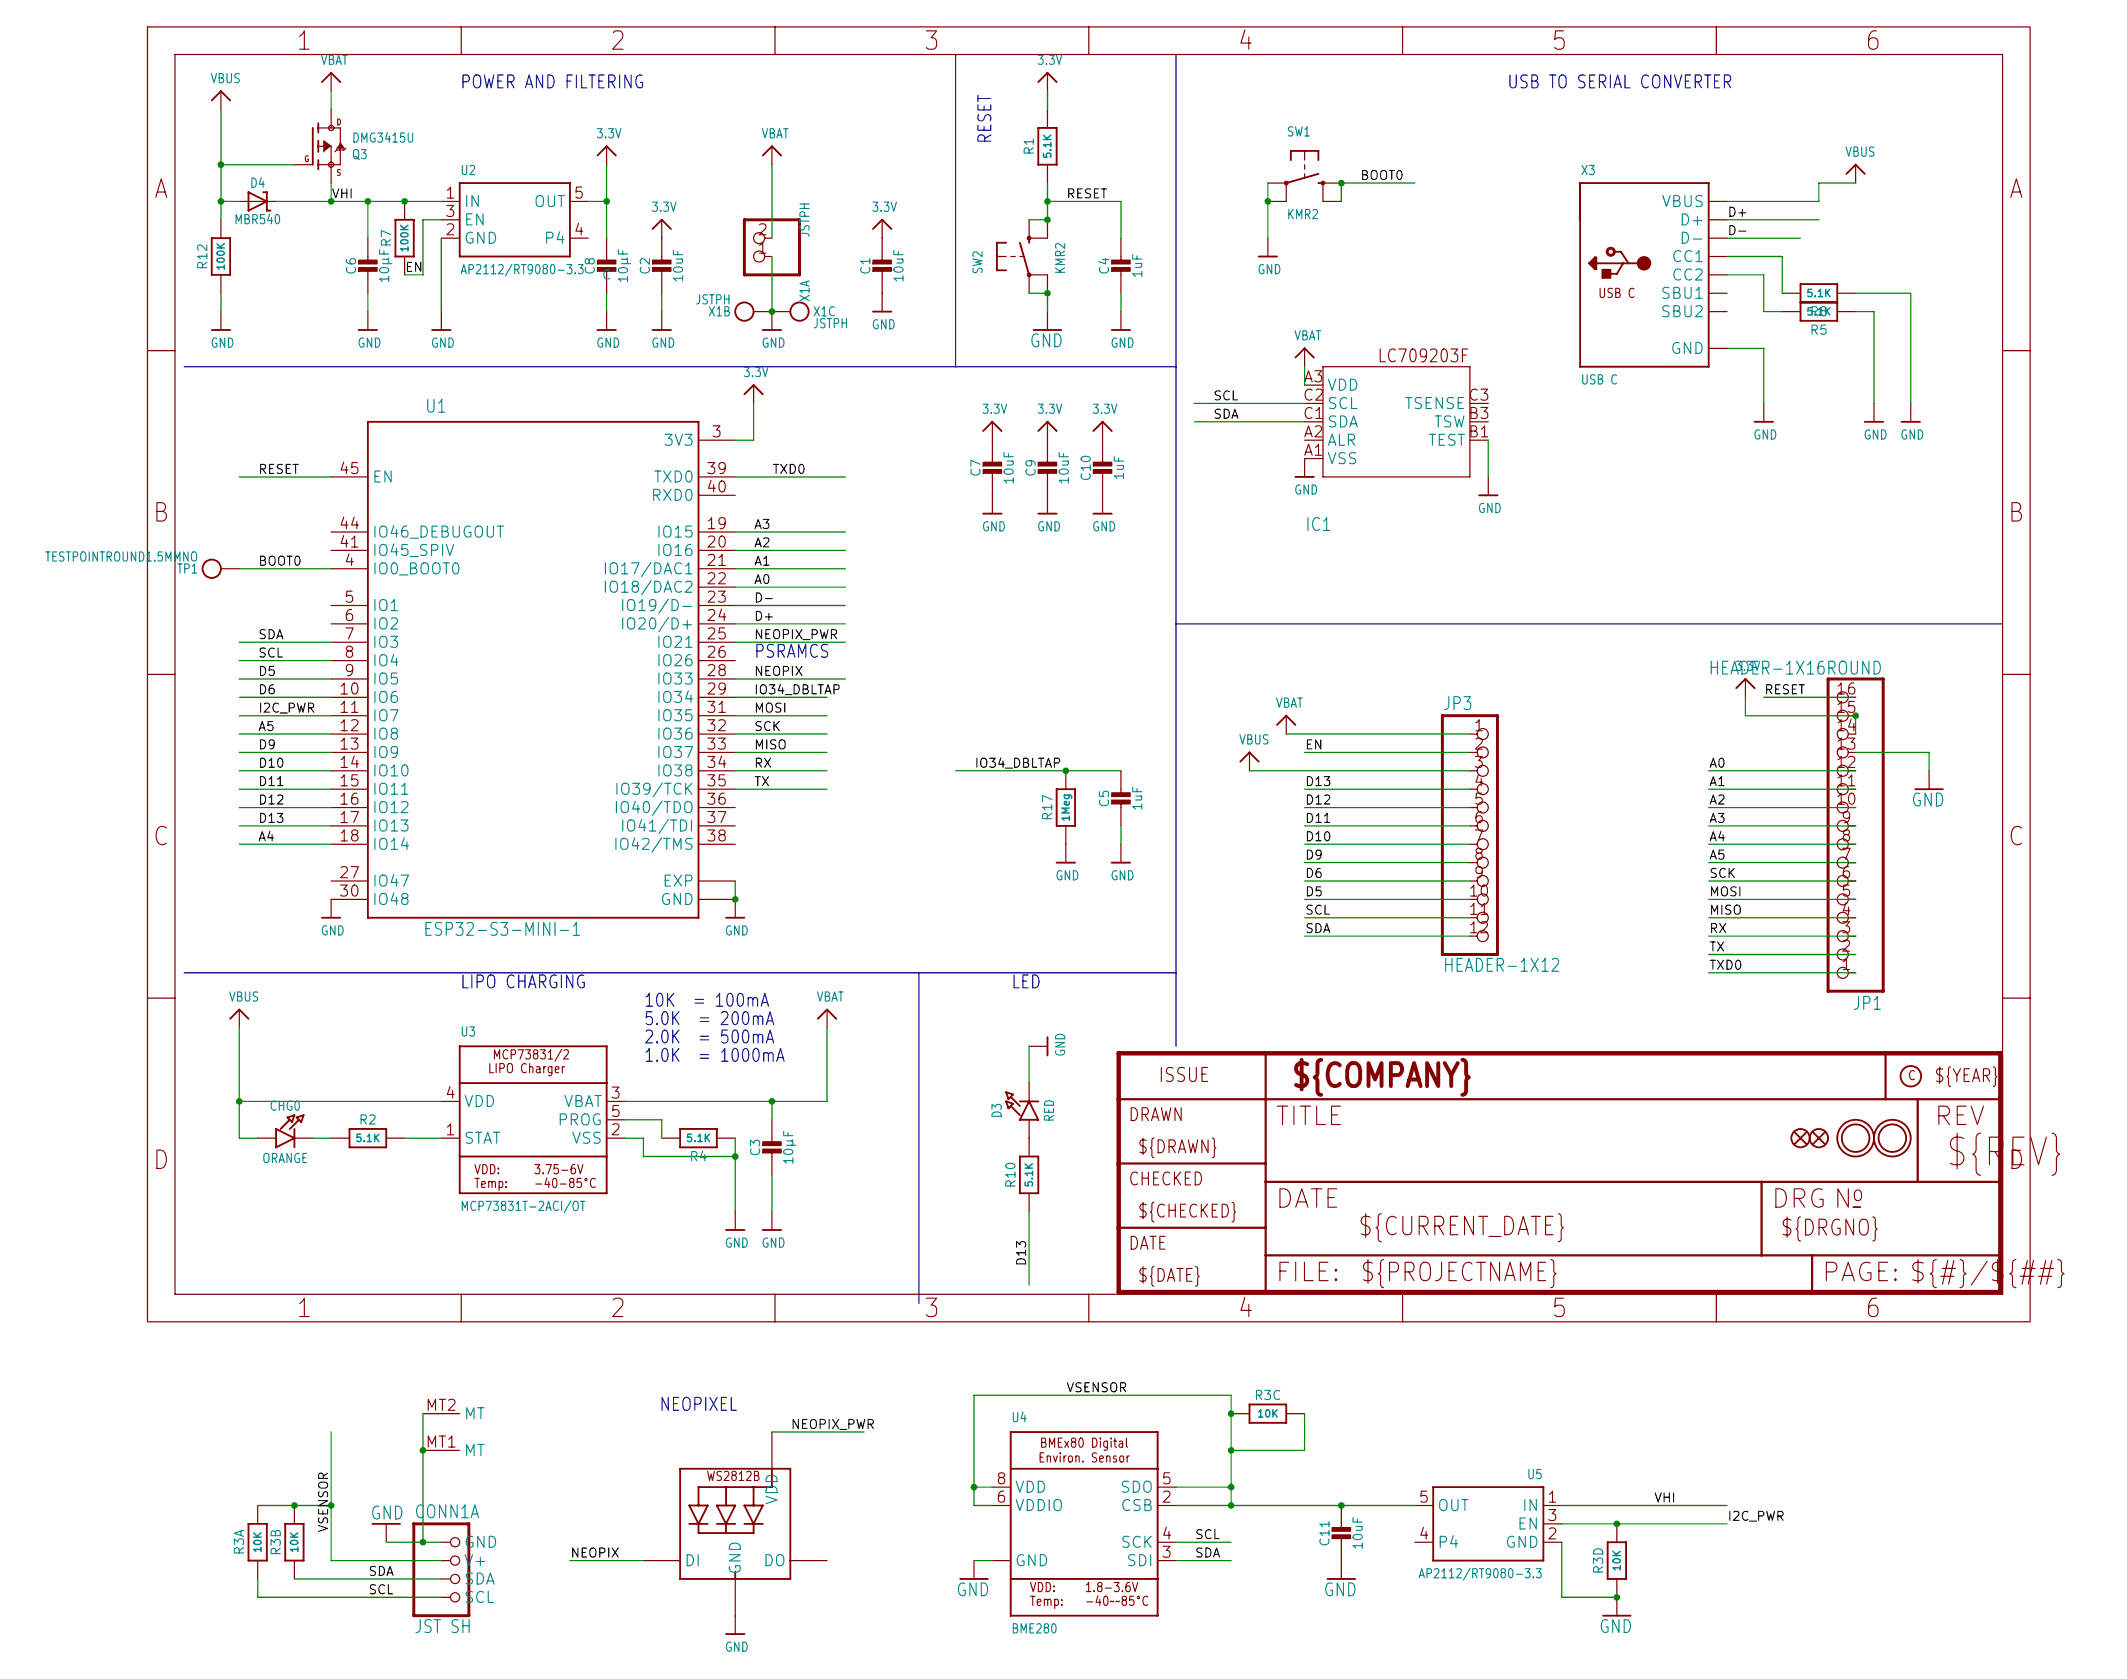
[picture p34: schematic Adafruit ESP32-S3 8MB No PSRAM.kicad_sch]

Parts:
C1, C2, C7, C9: 10uF; 0805-NO
C3, C6, C8: 10µF; 0805-NO
C4, C5, C10: 1uF; 0603-NO
C11: 10uF; _0805MP
CHG0: ORANGE; CHIPLED_0603_NOOUTLINE
CONN1: JST SH; JST_SH4_RA
D3: RED; CHIPLED_0603_NOOUTLINE
D4: MBR540; SOD-123
IC1: LC709203F/MH; WLCSP9
JP1: HEADER-1X16ROUND; 1X16_ROUND
JP3: HEADER-1X12; 1X12_ROUND
LED1: WS2812B_SK6805_1515; SK6805_1515
Q3: DMG3415U; SOT23-R
R1, R2, R4, R5, R8, R10: 5.1K; 0603-NO
R3: 10K; RESPACK_4X0603
R7, R12: 100K; 0603-NO
R17: 1Meg; 0603-NO
SW1, SW2: KMR2; BTN_KMR2_4.6X2.8
TP1: TESTPOINTROUND1.5MMNO; TESTPOINT_ROUND_1.5MM_NO
U1: ESP32-S3-MINI-1; QFN60_ESP32-S2-MINI-1_EXP
U2, U5: AP2112/RT9080-3.3; SOT23-5
U3: MCP73831T-2ACI/OT; SOT23-5
U4: BME280
U$31, U$32: MOUNTINGHOLE2.5; MOUNTINGHOLE_2.5_PLATED
U$34, U$35: FIDUCIAL_1MM
X1: JSTPH; JSTPH2_BATT
X3: USB C; USB_C_CUSB31-CFM2AX-01-X

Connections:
3.3V: C1.1, C2.1, C7.1, C8.1, C9.1, C10.1, JP1.14, JP1.15, R1.2, U1.3 (3V3), U2.5 (OUT)
A0: JP1.12, U1.22 (IO18/DAC2)
A1: JP1.11, U1.21 (IO17/DAC1)
A2: JP1.10, U1.20 (IO16)
A3: JP1.9, U1.19 (IO15)
A4: JP1.8, U1.18 (IO14)
A5: JP1.7, U1.12 (IO8)
BOOT0: SW1.B (S), SW1.B' (S1), TP1.P$1, U1.4 (IO0_BOOT0)
D5: JP3.10, U1.9 (IO5)
D6: JP3.9, U1.10 (IO6)
D9: JP3.8, U1.13 (IO9)
D10: JP3.7, U1.14 (IO10)
D11: JP3.6, U1.15 (IO11)
D12: JP3.5, U1.16 (IO12)
D13: JP3.4, R10.1, U1.17 (IO13)
D+: U1.24 (IO20/D+), X3.A6 (D+), X3.B6 (D+)
D-: U1.23 (IO19/D-), X3.A7 (D-), X3.B7 (D-)
EN: JP3.2, R7.1, U2.3 (EN)
GND: C1.2, C2.2, C3.2, C4.2, C5.2, C6.2, C7.2, C8.2, C9.2, C10.2, C11.2, CONN1.1 (GND), CONN1.MT1 (MT), CONN1.MT2 (MT), D3.C, IC1.A1 (VSS), IC1.B1 (TEST), JP1.13, LED1.4 (GND), R3.4 (1), R4.1, R5.1, R8.1, R12.1, R17.1, SW1.A, SW1.A' (P1), SW2.A, SW2.A' (P1), U1.1 (GND), U1.2 (GND), U1.30 (IO48), U1.42 (GND), U1.43 (GND), U1.46 (GND), U1.47 (GND), U1.48 (GND), U1.49 (GND), U1.50 (GND), U1.51 (GND), U1.52 (GND), U1.53 (GND), U1.54 (GND), U1.55 (GND), U1.56 (GND), U1.57 (GND), U1.58 (GND), U1.59 (GND), U1.60 (GND), U1.61 (EXP), U1.62 (GND), U1.63 (GND), U1.64 (GND), U1.65 (GND), U1.66 (EXP), U1.67 (EXP), U1.68 (EXP), U1.69 (EXP), U1.70 (EXP), U1.71 (EXP), U1.72 (EXP), U1.73 (EXP), U2.2 (GND), U3.2 (VSS), U4.1 (GND), U4.7 (GND), U5.2 (GND), X1.1, X1.NC1, X1.NC2, X3.A1B12 (GND), X3.B1A12 (GND)
I2C_PWR: R3.5 (2), U1.11 (IO7), U5.3 (EN)
IO34_DBLTAP: C5.1, R17.2, U1.29 (IO34)
MISO: JP1.4, U1.33 (IO37)
MOSI: JP1.5, U1.31 (IO35)
unnamed: CHG0.C, R2.1
unnamed: R2.2, U3.1 (STAT)
unnamed: R4.2, U3.5 (PROG)
unnamed: D3.A, R10.2
unnamed: R8.2, X3.A5 (CC1)
unnamed: R5.2, X3.B5 (CC2)
NEOPIX: LED1.1 (DI), U1.28 (IO33)
NEOPIX_PWR: LED1.2 (VDD), U1.25 (IO21)
RESET: C4.1, JP1.16, R1.1, SW2.B (S), SW2.B' (S1), U1.45 (EN)
RX: JP1.3, U1.34 (IO38)
SCK: JP1.6, U1.32 (IO36)
SCL: CONN1.4 (SCL), IC1.C2 (SCL), JP3.11, R3.1, U1.8 (IO4), U4.4 (SCK)
SDA: CONN1.3 (SDA), IC1.C1 (SDA), JP3.12, R3.2 (1), U1.7 (IO3), U4.3 (SDI)
TX: JP1.2, U1.35 (IO39/TCK)
TXD0: JP1.1, U1.39 (TXD0)
VBAT: C3.1, IC1.A3 (VDD), JP3.1, Q3.3 (D), U3.3 (VBAT), X1.2
VBUS: CHG0.A, D4.A, JP3.3, Q3.1 (G), R12.2, U3.4 (VDD), X3.A4B9 (VBUS), X3.B4A9 (VBUS)
VHI: C6.1, D4.C, Q3.2 (S), R7.2, U2.1 (IN), U5.1 (IN)
VSENSOR: C11.1, CONN1.2 (V+), R3.3 (1), R3.6 (2), R3.7 (2), R3.8 (2), U4.2 (CSB), U4.5 (SDO), U4.6 (VDDIO), U4.8 (VDD), U5.5 (OUT)

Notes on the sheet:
NEOPIXEL
5.0K = 200mA
RESET
1.0K = 1000mA
POWER AND FILTERING
LIPO CHARGING
USB TO SERIAL CONVERTER
2.0K = 500mA
PSRAMCS
10K = 100mA
LED

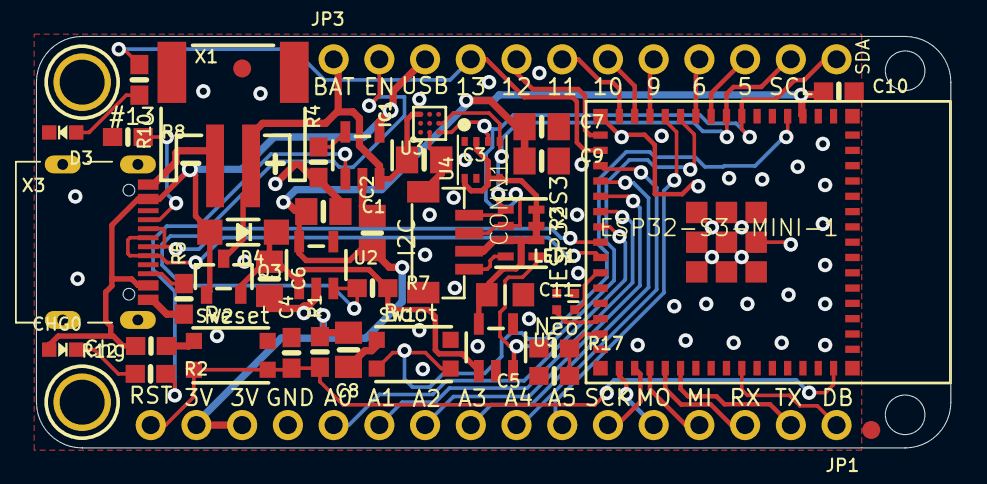
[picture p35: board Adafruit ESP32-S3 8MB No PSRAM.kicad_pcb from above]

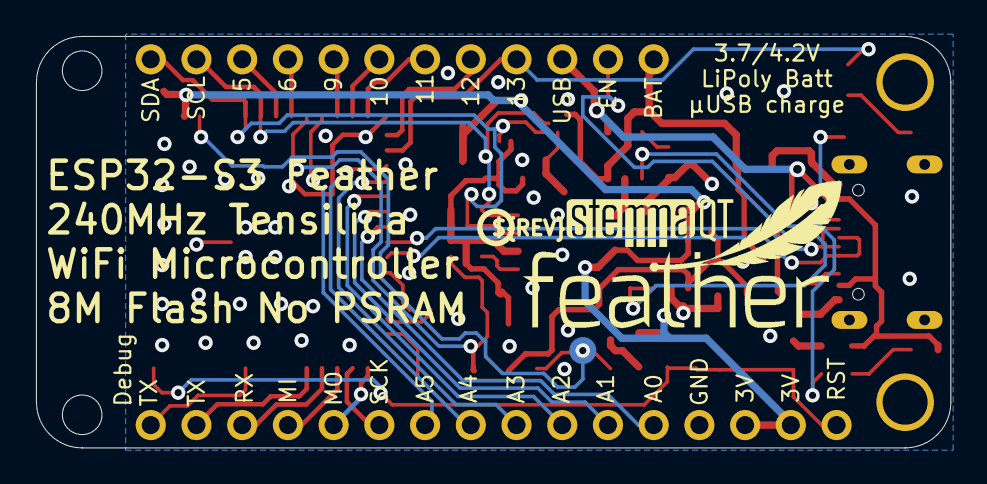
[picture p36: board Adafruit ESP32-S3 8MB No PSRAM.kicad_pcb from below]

Board: 2 copper layers, 50.8 x 22.9 mm, 49 parts (4 on the bottom side), 42 nets.

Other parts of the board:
U$14: PCBFEAT-REV-040
U$15: FEATHERLOGO_MED
U$53: STEMMAQT
UNK_HOLE_0: dummyfp0
UNK_HOLE_1: dummyfp1

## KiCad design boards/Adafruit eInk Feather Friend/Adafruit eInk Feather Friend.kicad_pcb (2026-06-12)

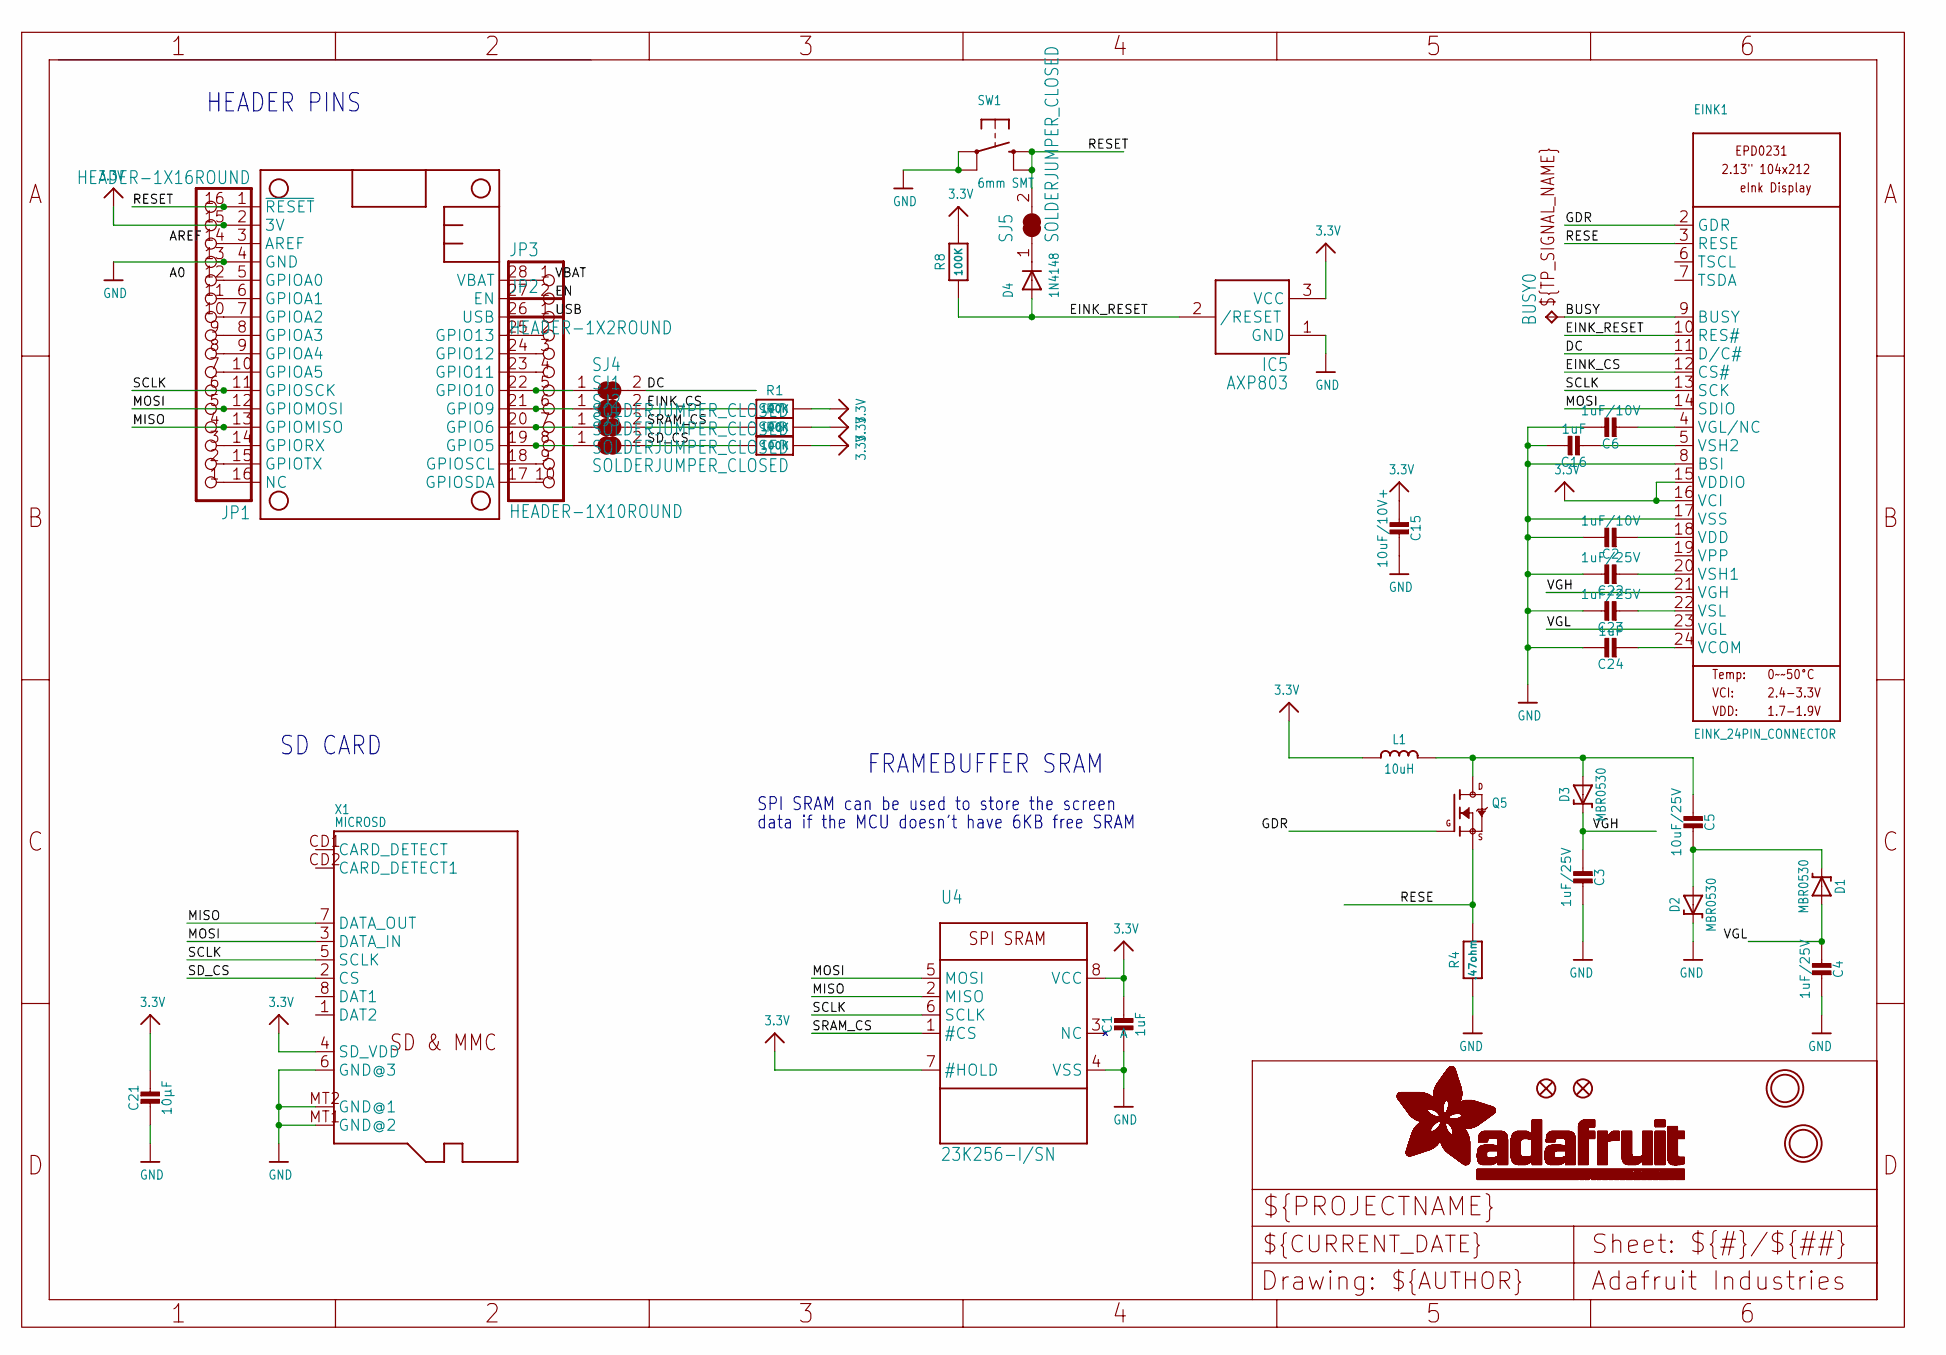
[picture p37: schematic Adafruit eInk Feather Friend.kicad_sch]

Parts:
BUSY0: TPTP15SQ; TP15SQ
C1: 1uF; 0805_10MGAP
C2, C6: 1uF/10V; 0805-NO
C3, C4, C22, C23: 1uF/25V; 0805-NO
C5: 10uF/25V; 0805-NO
C15: 10uF/10V+; 0805-NO
C16, C24: 1uF; 0805-NO
C21: 10µF; 0805-NO
D1, D2, D3: MBR0530; SOD-123
D4: 1N4148; SOD-323F
EINK1: EINK_24PIN_CONNECTOR; EINK_24PIN
FID1, FID3: FIDUCIAL_1MM
IC5: AXP803; SOT23
JP1: HEADER-1X16ROUND; 1X16_ROUND
JP2: HEADER-1X10ROUND; 1X10_ROUND
JP3: HEADER-1X2ROUND; 1X02_ROUND
L1: 10uH; INDUCTOR_4X4MM_NR401
MS1: FEATHERWING_NOHOLES
Q5: IRLML0100; SOT23-3
R1, R6, R7, R8: 100K; 0603-NO
R4: .47ohm; 0805_10MGAP
SJ1, SJ2, SJ3, SJ4, SJ5: SOLDERJUMPER_CLOSED; SOLDERJUMPER_CLOSEDWIRE
SW1: 6mm SMT; BTN_KMR2_4.6X2.8
U4: 23K256-I/SN; SOIC8_150MIL
U$3, U$4: MOUNTINGHOLE2.5; MOUNTINGHOLE_2.5_PLATED
X1: MICROSD

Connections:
3.3V: C1.1, C15.2, C21.1, EINK1.15 (VDDIO), EINK1.16 (VCI), IC5.3 (VCC), JP1.15, L1.P$2 (2), MS1.2 (3V), R1.2, R6.2, R7.2, R8.2, U4.7 (#HOLD), U4.8 (VCC), X1.4 (SD_VDD)
A0: JP1.12, MS1.5 (GPIOA0)
AREF: JP1.14, MS1.3 (AREF)
BUSY: BUSY0.TP, EINK1.9 (BUSY)
DC: EINK1.11 (D/C#), SJ4.2
EINK_CS: EINK1.12 (CS#), R1.1, SJ1.2
EINK_RESET: D4.A, EINK1.10 (RES#), IC5.2 (/RESET), R8.1
EN: JP3.2, MS1.27 (EN)
GDR: EINK1.2 (GDR), Q5.1 (G)
GND: C1.2, C2.1, C3.2, C4.2, C6.1, C15.1, C16.1, C21.2, C22.1, C23.1, C24.1, D2.C, EINK1.8 (BSI), EINK1.17 (VSS), IC5.1 (GND), JP1.13, MS1.4 (GND), R4.2, SW1.A, SW1.A' (P1), U4.4 (VSS), X1.6 (GND@3), X1.MT1 (GND@2), X1.MT2 (GND@1)
H: JP2.8, MS1.19 (GPIO5), SJ3.1
I: JP2.7, MS1.20 (GPIO6), SJ2.1
J: JP2.6, MS1.21 (GPIO9), SJ1.1
K: JP2.5, MS1.22 (GPIO10), SJ4.1
MISO: JP1.4, MS1.13 (GPIOMISO), U4.2 (MISO), X1.7 (DATA_OUT)
MOSI: EINK1.14 (SDIO), JP1.5, MS1.12 (GPIOMOSI), U4.5 (MOSI), X1.3 (DATA_IN)
unnamed: JP1.7, MS1.10 (GPIOA5)
unnamed: C5.2, D1.C, D2.A
unnamed: C5.1, D3.A, L1.P$1 (1), Q5.3 (D)
unnamed: C16.2, EINK1.5 (VSH2)
unnamed: C2.2, EINK1.18 (VDD)
unnamed: C22.2, EINK1.20 (VSH1)
unnamed: D4.C, SJ5.1
unnamed: JP1.11, MS1.6 (GPIOA1)
unnamed: C6.2, EINK1.4 (VGL/NC)
unnamed: JP1.10, MS1.7 (GPIOA2)
unnamed: JP1.9, MS1.8 (GPIOA3)
unnamed: JP1.8, MS1.9 (GPIOA4)
unnamed: JP1.3, MS1.14 (GPIORX)
unnamed: JP1.2, MS1.15 (GPIOTX)
unnamed: JP1.1, MS1.16 (NC)
unnamed: JP2.10, MS1.17 (GPIOSDA)
unnamed: JP2.9, MS1.18 (GPIOSCL)
unnamed: JP2.4, MS1.23 (GPIO11)
unnamed: JP2.3, MS1.24 (GPIO12)
unnamed: JP2.2, MS1.25 (GPIO13)
unnamed: C23.2, EINK1.22 (VSL)
unnamed: C24.2, EINK1.24 (VCOM)
RESE: EINK1.3 (RESE), Q5.2 (S), R4.1
RESET: JP1.16, MS1.1 (~RESET), SJ5.2, SW1.B (S), SW1.B' (S1)
SCLK: EINK1.13 (SCK), JP1.6, MS1.11 (GPIOSCK), U4.6 (SCLK), X1.5 (SCLK)
SD_CS: R6.1, SJ3.2, X1.2 (CS)
SRAM_CS: R7.1, SJ2.2, U4.1 (#CS)
USB: JP2.1, MS1.26 (USB)
VBAT: JP3.1, MS1.28 (VBAT)
VGH: C3.1, D3.C, EINK1.21 (VGH)
VGL: C4.1, D1.A, EINK1.23 (VGL)

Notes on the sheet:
FRAMEBUFFER SRAM
SPI SRAM can be used to store the screen
HEADER PINS
data if the MCU doesn't have 6KB free SRAM
SD CARD

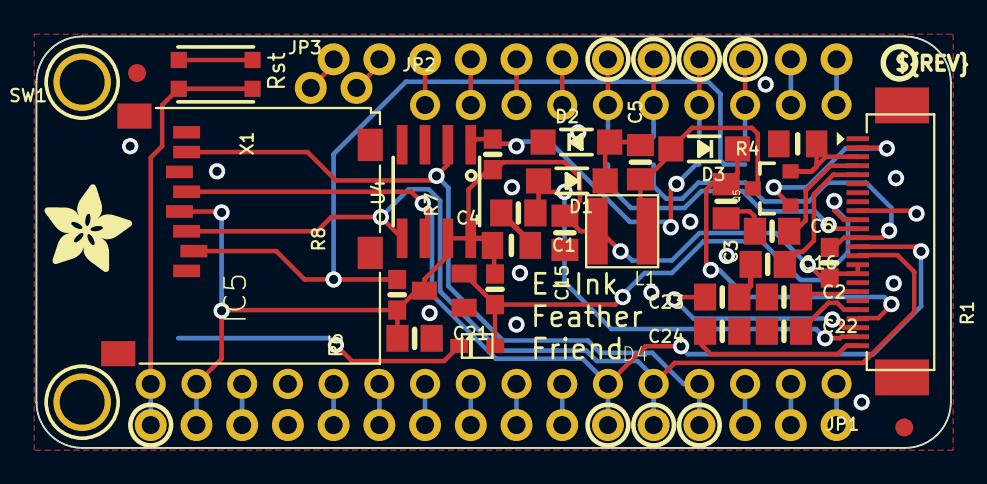
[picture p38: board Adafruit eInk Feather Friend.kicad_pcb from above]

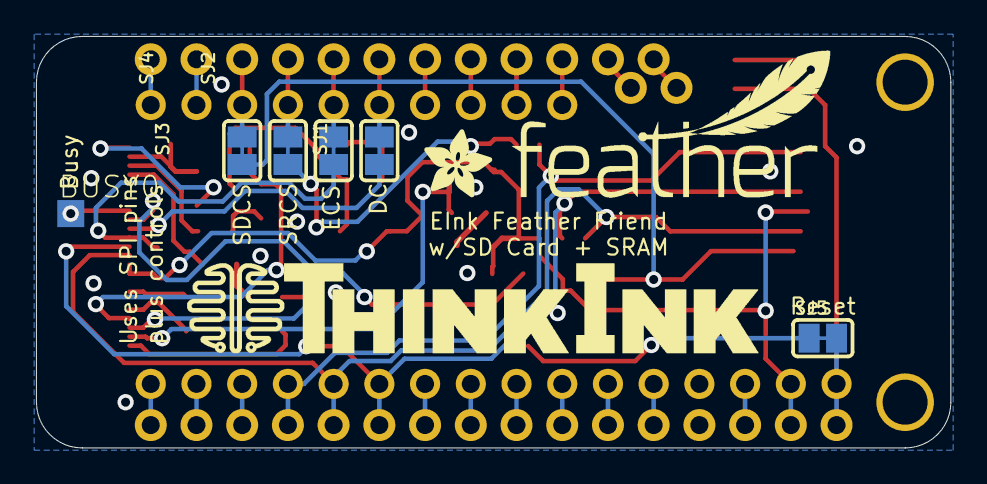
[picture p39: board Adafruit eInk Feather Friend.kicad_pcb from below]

Board: 2 copper layers, 50.8 x 22.9 mm, 47 parts (9 on the bottom side), 47 nets.

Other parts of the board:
U$5: THINKINK_1.25IN
U$6: FEATHERLOGO_MED
U$8: ADAFRUIT_5MM
U$9: PCBFEAT-REV-040
U$17: ADAFRUIT_3.5MM

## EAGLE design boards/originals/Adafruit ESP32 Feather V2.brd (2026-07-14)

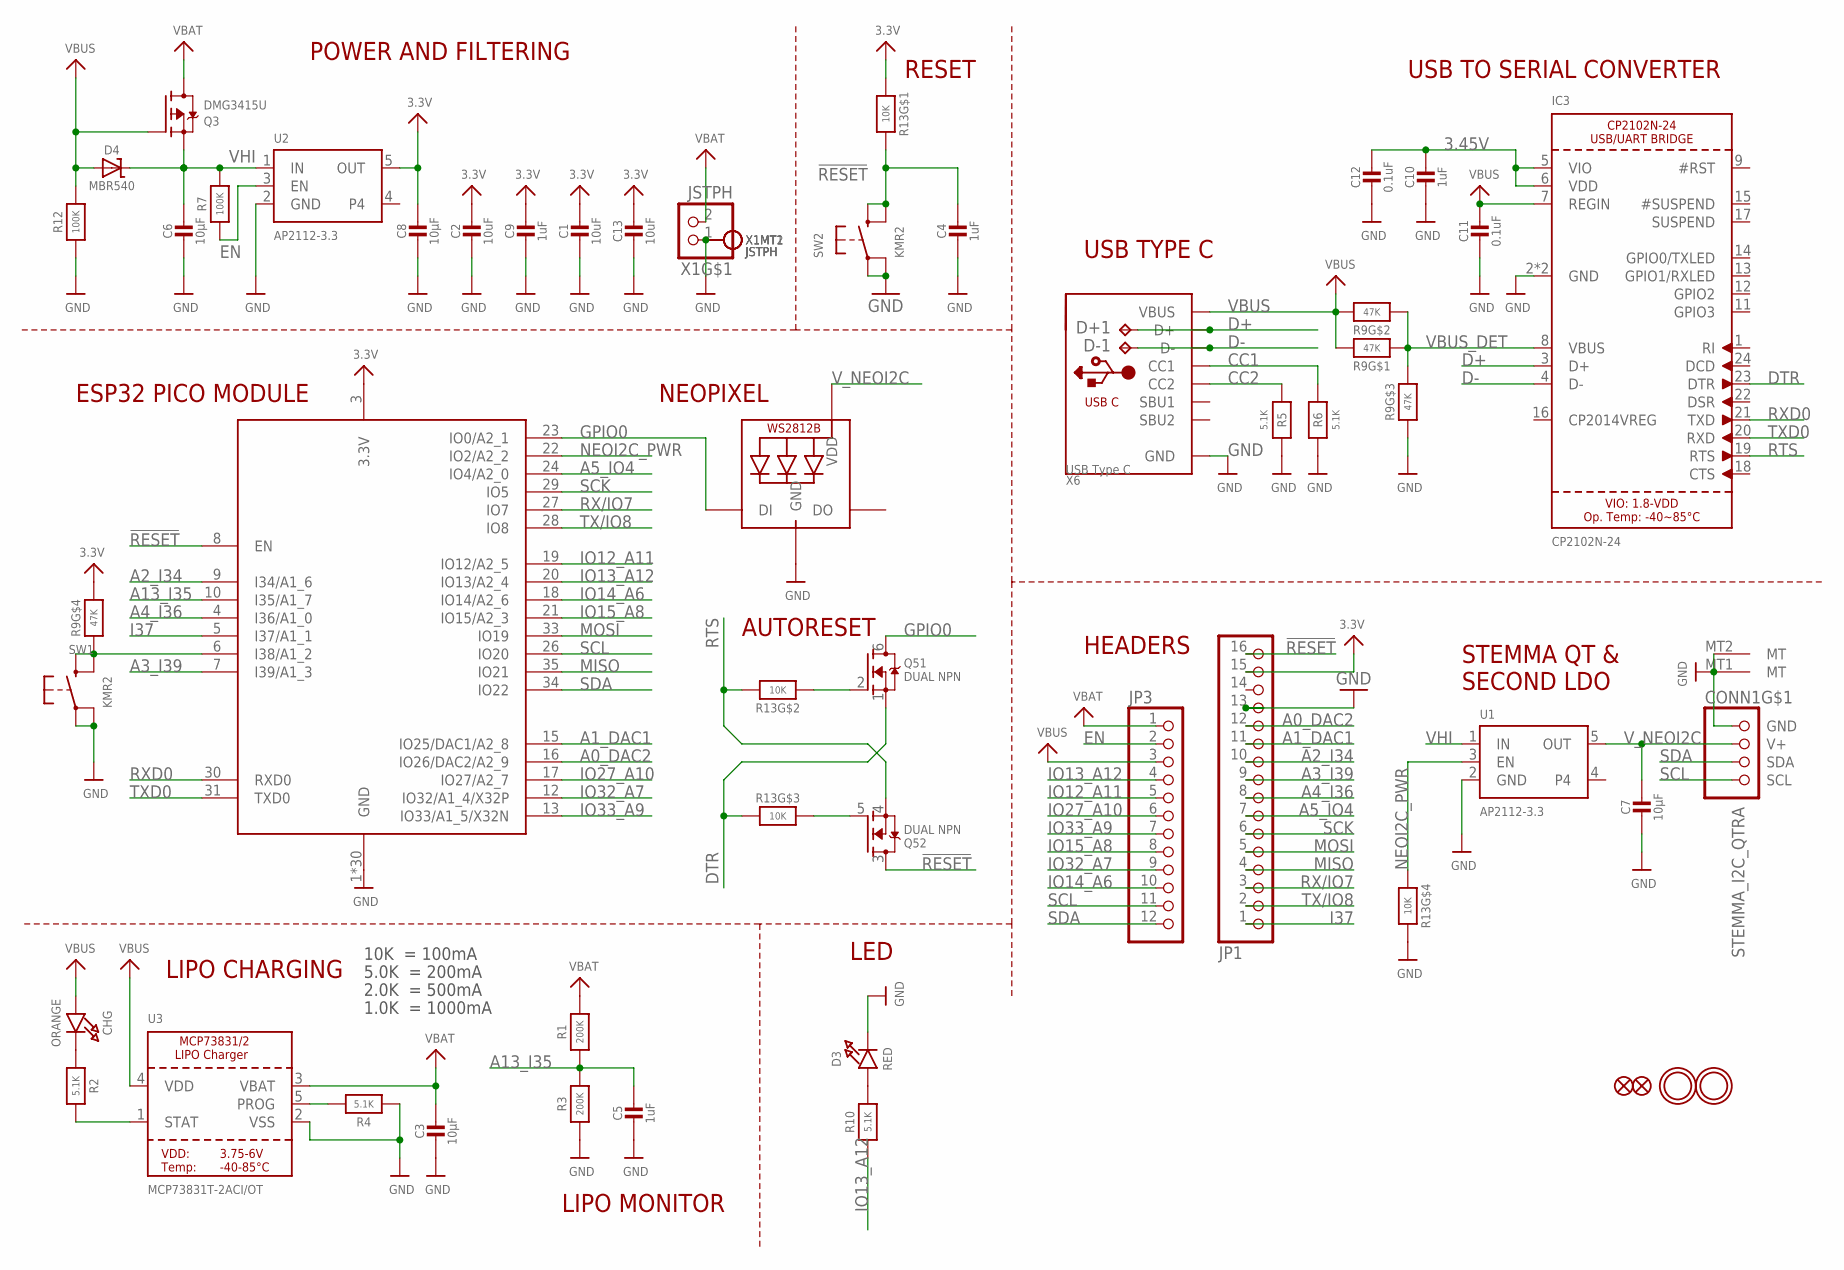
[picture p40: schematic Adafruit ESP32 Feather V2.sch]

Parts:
C1, C2, C13: 10uF; 0805-NO
C3, C6, C7, C8: 10µF; 0805-NO
C4, C5, C9, C10: 1uF; 0603-NO
C11, C12: 0.1uF; 0603-NO
CHG: ORANGE; CHIPLED_0603_NOOUTLINE
CONN1: STEMMA_I2C_QTRA; JST_SH4_RA
D3: RED; CHIPLED_0603_NOOUTLINE
D4: MBR540; SOD-123
D+1: TPB1,27; B1,27
D-1: TPB1,27; B1,27
IC3: CP2102N-24; QFN24_4MM_SMSC
JP1: HEADER-1X16ROUND; 1X16_ROUND
JP3: HEADER-1X12; 1X12_ROUND
LED1: WS2812B3535; LED3535
Q3: DMG3415U; SOT23-R
Q5: DUAL NPN; SOT363
R1, R3: 200K; 0603-NO
R2, R4, R5, R6, R10: 5.1K; 0603-NO
R7, R12: 100K; 0603-NO
R9: 47K; RESPACK_4X0603
R13: 10K; RESPACK_4X0603
SW1, SW2: KMR2; BTN_KMR2_4.6X2.8
U1, U2: AP2112-3.3; SOT23-5
U3: MCP73831T-2ACI/OT; SOT23-5
U$31, U$32: MOUNTINGHOLE2.5; MOUNTINGHOLE_2.5_PLATED
U$34, U$35: FIDUCIAL_1MM
X1: JSTPH; JSTPH2_BATT
X3: ESP32-PICO-MINI-02MINI; ESP32-PICO-MINI
X6: USB Type C; USB_C_CUSB31-CFM2AX-01-X

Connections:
3.3V: C1.1, C2.1, C8.1, C9.1, C13.1, JP1.15, R9.5 (2), R13.1, U2.5 (OUT), X3.3 (3.3V)
3.45V: C10.1, C12.1, IC3.5 (VIO), IC3.6 (VDD)
!RESET: C4.1, JP1.16, Q5.3 (D), R13.8 (2), SW2.B (S), SW2.B' (S1), X3.8 (EN)
A0_DAC2: JP1.12, X3.16 (IO26/DAC2/A2_9)
A1_DAC1: JP1.11, X3.15 (IO25/DAC1/A2_8)
A2_I34: JP1.10, X3.9 (I34/A1_6)
A3_I39: JP1.9, X3.7 (I39/A1_3)
A4_I36: JP1.8, X3.4 (I36/A1_0)
A5_IO4: JP1.7, X3.24 (IO4/A2_0)
A13_I35: C5.1, R1.1, R3.2, X3.10 (I35/A1_7)
CC1: R6.2, X6.A5 (CC1)
CC2: R5.2, X6.B5 (CC2)
D+: D+1.TP, IC3.3 (D+), X6.A6 (D+), X6.B6 (D+)
D-: D-1.TP, IC3.4 (D-), X6.A7 (D-), X6.B7 (D-)
DTR: IC3.23 (DTR), Q5.1 (S), R13.3 (1)
EN: JP3.2, R7.1, U2.3 (EN)
GND: C1.2, C2.2, C3.2, C4.2, C5.2, C6.2, C7.2, C8.2, C9.2, C10.2, C11.2, C12.2, C13.2, CONN1.1 (GND), CONN1.MT1 (MT), CONN1.MT2 (MT), D3.C, IC3.2 (GND), IC3.THERM (GND), JP1.13, LED1.4 (GND), R3.1, R4.1, R5.1, R6.1, R9.3 (1), R12.1, R13.5 (2), SW1.A, SW1.A' (P1), SW2.A, SW2.A' (P1), U1.2 (GND), U2.2 (GND), U3.2 (VSS), X1.1, X1.NC1, X1.NC2, X3.1 (GND), X3.2 (GND), X3.11 (GND), X3.14 (GND), X3.36 (GND), X3.37 (GND), X3.38 (GND), X3.39 (GND), X3.40 (GND), X3.41 (GND), X3.42 (GND), X3.43 (GND), X3.44 (GND), X3.45 (GND), X3.46 (GND), X3.47 (GND), X3.48 (GND), X3.49 (GND), X3.50 (GND), X3.51 (GND), X3.52 (GND), X3.53 (GND), X3.54 (GND), X3.55 (GND), X3.56 (GND), X3.57 (GND), X3.58 (GND), X3.59 (GND), X3.60 (GND), X3.61 (GND), X6.A1B12 (GND), X6.B1A12 (GND)
GPIO0: LED1.1 (DI), Q5.6 (D), X3.23 (IO0/A2_1)
I37: JP1.1, X3.5 (I37/A1_1)
IO12_A11: JP3.5, X3.19 (IO12/A2_5)
IO13_A12: JP3.4, R10.1, X3.20 (IO13/A2_4)
IO14_A6: JP3.10, X3.18 (IO14/A2_6)
IO15_A8: JP3.8, X3.21 (IO15/A2_3)
IO27_A10: JP3.6, X3.17 (IO27/A2_7)
IO32_A7: JP3.9, X3.12 (IO32/A1_4/X32P)
IO33_A9: JP3.7, X3.13 (IO33/A1_5/X32N)
MISO: JP1.4, X3.35 (IO21)
MOSI: JP1.5, X3.33 (IO19)
unnamed: CHG.C, R2.1
unnamed: R2.2, U3.1 (STAT)
unnamed: R4.2, U3.5 (PROG)
unnamed: D3.A, R10.2
unnamed: R9.4 (1), SW1.B (S), SW1.B' (S1), X3.6 (I38/A1_2)
unnamed: Q5.5 (G), R13.6 (2)
unnamed: Q5.2 (G), R13.2 (1)
NEOI2C_PWR: R13.4 (1), U1.3 (EN), X3.22 (IO2/A2_2)
RTS: IC3.19 (RTS), Q5.4 (S), R13.7 (2)
RX/IO7: JP1.3, X3.27 (IO7)
RXD0: IC3.21 (TXD), X3.30 (RXD0)
SCK: JP1.6, X3.29 (IO5)
SCL: CONN1.4 (SCL), JP3.11, X3.26 (IO20)
SDA: CONN1.3 (SDA), JP3.12, X3.34 (IO22)
TX/IO8: JP1.2, X3.28 (IO8)
TXD0: IC3.20 (RXD), X3.31 (TXD0)
VBAT: C3.1, JP3.1, Q3.3 (D), R1.2, U3.3 (VBAT), X1.2
VBUS: C11.1, CHG.A, D4.A, IC3.7 (REGIN), JP3.3, Q3.1 (G), R9.7 (2), R9.8 (2), R12.2, U3.4 (VDD), X6.A4B9 (VBUS), X6.B4A9 (VBUS)
VBUS_DET: IC3.8 (VBUS), R9.1, R9.2 (1), R9.6 (2)
VHI: C6.1, D4.C, Q3.2 (S), R7.2, U1.1 (IN), U2.1 (IN)
V_NEOI2C: C7.1, CONN1.2 (V+), LED1.2 (VDD), U1.5 (OUT)

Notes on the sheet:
POWER AND FILTERING
RESET
10K = 100mA
5.0K = 200mA
2.0K = 500mA
1.0K = 1000mA
USB TO SERIAL CONVERTER
LIPO CHARGING
LED
ESP32 PICO MODULE
LIPO MONITOR
HEADERS
STEMMA QT & SECOND LDO
USB TYPE C
AUTORESET
NEOPIXEL



Board: 2 copper layers, 50.8 x 22.9 mm, 54 parts (6 on the bottom side), 49 nets.

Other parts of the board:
U$7: ADAFRUIT_5MM
U$9: FEATHERLOGO_MED
U$13: PCBFEAT-REV-040
U$14: ADAFRUIT_2.5MM
U$15: ADAFRUIT_3.5MM
U$43: HUZZAH32

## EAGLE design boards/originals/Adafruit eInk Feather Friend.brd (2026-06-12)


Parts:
BUSY: TPTP15SQ; TP15SQ
C1: 1uF; 0805_10MGAP
C2, C6: 1uF/10V; 0805-NO
C3, C4, C22, C23: 1uF/25V; 0805-NO
C5: 10uF/25V; 0805-NO
C15: 10uF/10V+; 0805-NO
C16, C24: 1uF; 0805-NO
C21: 10µF; 0805-NO
D1, D2, D3: MBR0530; SOD-123
D4: 1N4148; SOD-323F
EINK1: EINK_24PIN_CONNECTOR; EINK_24PIN
FID1, FID3: FIDUCIAL_1MM
IC5: AXP803; SOT23
JP1: HEADER-1X16ROUND; 1X16_ROUND
JP2: HEADER-1X10ROUND; 1X10_ROUND
JP3: HEADER-1X2ROUND; 1X02_ROUND
L1: 10uH; INDUCTOR_4X4MM_NR401
MS1: FEATHERWING_NOHOLES
Q5: IRLML0100; SOT23-3
R1, R6, R7, R8: 100K; 0603-NO
R4: .47ohm; 0805_10MGAP
SJ1, SJ2, SJ3, SJ4, SJ5: SOLDERJUMPER_CLOSED; SOLDERJUMPER_CLOSEDWIRE
SW1: 6mm SMT; BTN_KMR2_4.6X2.8
U4: 23K256-I/SN; SOIC8_150MIL
U$3, U$4: MOUNTINGHOLE2.5; MOUNTINGHOLE_2.5_PLATED
X1: MICROSD

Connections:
3.3V: C1.1, C15.2, C21.1, EINK1.15 (VDDIO), EINK1.16 (VCI), IC5.3 (VCC), JP1.15, L1.P$2 (2), MS1.2 (3V), R1.2, R6.2, R7.2, R8.2, U4.7 (#HOLD), U4.8 (VCC), X1.4 (SD_VDD)
A0: JP1.12, MS1.5 (GPIOA0)
AREF: JP1.14, MS1.3 (AREF)
BUSY: BUSY.TP, EINK1.9 (BUSY)
DC: EINK1.11 (D/C#), SJ4.2
EINK_CS: EINK1.12 (CS#), R1.1, SJ1.2
EINK_RESET: D4.A, EINK1.10 (RES#), IC5.2 (/RESET), R8.1
EN: JP3.2, MS1.27 (EN)
GDR: EINK1.2 (GDR), Q5.1 (G)
GND: C1.2, C2.1, C3.2, C4.2, C6.1, C15.1, C16.1, C21.2, C22.1, C23.1, C24.1, D2.C, EINK1.8 (BSI), EINK1.17 (VSS), IC5.1 (GND), JP1.13, MS1.4 (GND), R4.2, SW1.A, SW1.A' (P1), U4.4 (VSS), X1.6 (GND), X1.MT1 (GND), X1.MT2 (GND)
H: JP2.8, MS1.19 (GPIO5), SJ3.1
I: JP2.7, MS1.20 (GPIO6), SJ2.1
J: JP2.6, MS1.21 (GPIO9), SJ1.1
K: JP2.5, MS1.22 (GPIO10), SJ4.1
MISO: JP1.4, MS1.13 (GPIOMISO), U4.2 (MISO), X1.7 (DATA_OUT)
MOSI: EINK1.14 (SDIO), JP1.5, MS1.12 (GPIOMOSI), U4.5 (MOSI), X1.3 (DATA_IN)
unnamed: JP1.7, MS1.10 (GPIOA5)
unnamed: C5.2, D1.C, D2.A
unnamed: C5.1, D3.A, L1.P$1 (1), Q5.3 (D)
unnamed: C16.2, EINK1.5 (VSH2)
unnamed: C2.2, EINK1.18 (VDD)
unnamed: C22.2, EINK1.20 (VSH1)
unnamed: D4.C, SJ5.1
unnamed: JP1.11, MS1.6 (GPIOA1)
unnamed: C6.2, EINK1.4 (VGL/NC)
unnamed: JP1.10, MS1.7 (GPIOA2)
unnamed: JP1.9, MS1.8 (GPIOA3)
unnamed: JP1.8, MS1.9 (GPIOA4)
unnamed: JP1.3, MS1.14 (GPIORX)
unnamed: JP1.2, MS1.15 (GPIOTX)
unnamed: JP1.1, MS1.16 (NC)
unnamed: JP2.10, MS1.17 (GPIOSDA)
unnamed: JP2.9, MS1.18 (GPIOSCL)
unnamed: JP2.4, MS1.23 (GPIO11)
unnamed: JP2.3, MS1.24 (GPIO12)
unnamed: JP2.2, MS1.25 (GPIO13)
unnamed: C23.2, EINK1.22 (VSL)
unnamed: C24.2, EINK1.24 (VCOM)
RESE: EINK1.3 (RESE), Q5.2 (S), R4.1
RESET: JP1.16, MS1.1 (!RESET), SJ5.2, SW1.B (S), SW1.B' (S1)
SCLK: EINK1.13 (SCK), JP1.6, MS1.11 (GPIOSCK), U4.6 (SCLK), X1.5 (SCLK)
SD_CS: R6.1, SJ3.2, X1.2 (CS)
SRAM_CS: R7.1, SJ2.2, U4.1 (#CS)
USB: JP2.1, MS1.26 (USB)
VBAT: JP3.1, MS1.28 (VBAT)
VGH: C3.1, D3.C, EINK1.21 (VGH)
VGL: C4.1, D1.A, EINK1.23 (VGL)

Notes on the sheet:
HEADER PINS
FRAMEBUFFER SRAM
SPI SRAM can be used to store the screen
data if the MCU doesn't have 6KB free SRAM
SD CARD



Board: 2 copper layers, 50.8 x 22.9 mm, 47 parts (9 on the bottom side), 47 nets.

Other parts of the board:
U$5: THINKINK_1.25IN
U$6: FEATHERLOGO_MED
U$8: ADAFRUIT_5MM
U$9: PCBFEAT-REV-040
U$17: ADAFRUIT_3.5MM

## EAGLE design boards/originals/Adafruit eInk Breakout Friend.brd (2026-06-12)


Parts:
C1: 1uF; 0805_10MGAP
C2, C3, C4, C6, C7, C16, C22, C23, C24: 1uF; 0805-NO
C5, C15: 10uF; 0805-NO
C20, C21: 10µF; 0805-NO
D1, D2, D3: MBR0530; SOD-123
EINK2: EINK_24PIN_CONNECTOR; EINK_24PIN
FID2, FID3: FIDUCIAL_1MM
JP1: HEADER-1X1276MIL; 1X12_ROUND_76MIL
L1: 10uH; INDUCTOR_4X4MM_NR401
Q5: IRLML0100; SOT23-3
R1, R3, R5, R6: 100K; 0603-NO
R2: 0.47ohm; 0805-NO
R4: 3 ohm; 0805-NO
SJ1: SOLDERJUMPER_2WAY; SOLDERJUMPER_2WAY_OPEN_NOPASTE
U1: 74LCX245; TSSOP20
U2: AP2112K-3.3; SOT23-5
U4: 23K256-I/SN; SOIC8_150MIL
U$3, U$4: MOUNTINGHOLE2.5; MOUNTINGHOLE_2.5_PLATED

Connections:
3.3V: C1.1, C15.2, C21.1, EINK2.15 (VDDIO), EINK2.16 (VCI), JP1.2, L1.P$2 (2), U1.1 (T/R), U1.20 (VCC), U2.5 (OUT), U4.7 (#HOLD), U4.8 (VCC)
BUSY: EINK2.9 (BUSY), JP1.11
DC: JP1.8, U1.5 (A4)
DC_3V: EINK2.11 (D/C#), U1.15 (B4)
DISPCS: JP1.7, R5.1, U1.4 (A3)
DISPCS_3V: EINK2.12 (CS#), U1.16 (B3)
ENABLE: JP1.12, R1.1, U2.3 (EN)
GDR: EINK2.2 (GDR), Q5.1 (G)
GND: C1.2, C2.1, C3.2, C4.2, C6.1, C7.1, C15.1, C16.1, C20.2, C21.2, C22.1, C23.1, C24.1, D2.C, EINK2.8 (BSI), EINK2.17 (VSS), JP1.3, R2.2, R4.2, U1.10 (GND), U1.19 (/OE), U2.2 (GND), U4.4 (VSS)
MISO: JP1.5, U4.2 (MISO)
MOSI: JP1.6, U1.3 (A2)
MOSI_3V: EINK2.14 (SDIO), U1.17 (B2), U4.5 (MOSI)
unnamed: C7.2, EINK2.19 (VPP)
unnamed: C5.2, D1.C, D2.A
unnamed: C5.1, D3.A, L1.P$1 (1), Q5.3 (D)
unnamed: C16.2, EINK2.5 (VSH2)
unnamed: C2.2, EINK2.18 (VDD)
unnamed: C22.2, EINK2.20 (VSH1)
unnamed: R4.1, SJ1.3
unnamed: C6.2, EINK2.4 (VGL/NC)
unnamed: C23.2, EINK2.22 (VSL)
unnamed: C24.2, EINK2.24 (VCOM)
RESE: EINK2.3 (RESE), Q5.2 (S), R2.1, SJ1.1, SJ1.2
RESET: JP1.10, R6.1, U1.8 (A7)
RESET_3V: EINK2.10 (RES#), U1.12 (B7)
SCLK: JP1.4, U1.2 (A1)
SCLK_3V: EINK2.13 (SCK), U1.18 (B1), U4.6 (SCLK)
SRAMCS: JP1.9, R3.1, U1.6 (A5)
SRAMCS_3V: U1.14 (B5), U4.1 (#CS)
TSCL: EINK2.6 (TSCL)
TSDA: EINK2.7 (TSDA)
VGH: C3.1, D3.C, EINK2.21 (VGH)
VGL: C4.1, D1.A, EINK2.23 (VGL)
VIN: C20.1, JP1.1, R1.2, R3.2, R5.2, R6.2, U2.1 (IN)

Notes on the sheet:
Pervasive Displays 2.0" Breakout
VOLTAGE REGULATOR
3/5V -> 3V LEVEL SHIFTING
HEADER PINS
FRAMEBUFFER SRAM
SPI SRAM can be used to store the screen
data if the MCU doesn't have 6KB free SRAM



Board: 2 copper layers, 34.3 x 21.6 mm, 37 parts (2 on the bottom side), 32 nets.

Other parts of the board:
U$2: ADAFRUIT_3.5MM
U$9: PCBFEAT-REV-040

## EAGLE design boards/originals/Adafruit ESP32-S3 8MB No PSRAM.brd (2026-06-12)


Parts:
C1, C2, C7, C9: 10uF; 0805-NO
C3, C6, C8: 10µF; 0805-NO
C4, C5, C10: 1uF; 0603-NO
C11: 10uF; _0805MP
CHG: ORANGE; CHIPLED_0603_NOOUTLINE
CONN1: JST SH; JST_SH4_RA
D3: RED; CHIPLED_0603_NOOUTLINE
D4: MBR540; SOD-123
IC1: LC709203F/MH; WLCSP9
JP1: HEADER-1X16ROUND; 1X16_ROUND
JP3: HEADER-1X12; 1X12_ROUND
LED1: WS2812B_SK6805_1515; SK6805_1515
Q3: DMG3415U; SOT23-R
R1, R2, R4, R5, R8, R10: 5.1K; 0603-NO
R3: 10K; RESPACK_4X0603
R7, R12: 100K; 0603-NO
R17: 1Meg; 0603-NO
SW1, SW2: KMR2; BTN_KMR2_4.6X2.8
TP1: TESTPOINTROUND1.5MMNO; TESTPOINT_ROUND_1.5MM_NO
U1: ESP32-S3-MINI-1; QFN60_ESP32-S2-MINI-1_EXP
U2, U5: AP2112/RT9080-3.3; SOT23-5
U3: MCP73831T-2ACI/OT; SOT23-5
U4: BME280
U$31, U$32: MOUNTINGHOLE2.5; MOUNTINGHOLE_2.5_PLATED
U$34, U$35: FIDUCIAL_1MM
X1: JSTPH; JSTPH2_BATT
X3: USB C; USB_C_CUSB31-CFM2AX-01-X

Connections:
3.3V: C1.1, C2.1, C7.1, C8.1, C9.1, C10.1, JP1.14, JP1.15, R1.2, U1.3 (3V3), U2.5 (OUT)
A0: JP1.12, U1.22 (IO18/DAC2)
A1: JP1.11, U1.21 (IO17/DAC1)
A2: JP1.10, U1.20 (IO16)
A3: JP1.9, U1.19 (IO15)
A4: JP1.8, U1.18 (IO14)
A5: JP1.7, U1.12 (IO8)
BOOT0: SW1.B (S), SW1.B' (S1), TP1.P$1, U1.4 (IO0_BOOT0)
D5: JP3.10, U1.9 (IO5)
D6: JP3.9, U1.10 (IO6)
D9: JP3.8, U1.13 (IO9)
D10: JP3.7, U1.14 (IO10)
D11: JP3.6, U1.15 (IO11)
D12: JP3.5, U1.16 (IO12)
D13: JP3.4, R10.1, U1.17 (IO13)
D+: U1.24 (IO20/D+), X3.A6 (D+), X3.B6 (D+)
D-: U1.23 (IO19/D-), X3.A7 (D-), X3.B7 (D-)
EN: JP3.2, R7.1, U2.3 (EN)
GND: C1.2, C2.2, C3.2, C4.2, C5.2, C6.2, C7.2, C8.2, C9.2, C10.2, C11.2, CONN1.1 (GND), CONN1.MT1 (MT), CONN1.MT2 (MT), D3.C, IC1.A1 (VSS), IC1.B1 (TEST), JP1.13, LED1.4 (GND), R3.4 (1), R4.1, R5.1, R8.1, R12.1, R17.1, SW1.A, SW1.A' (P1), SW2.A, SW2.A' (P1), U1.1 (GND), U1.2 (GND), U1.30 (IO48), U1.42 (GND), U1.43 (GND), U1.46 (GND), U1.47 (GND), U1.48 (GND), U1.49 (GND), U1.50 (GND), U1.51 (GND), U1.52 (GND), U1.53 (GND), U1.54 (GND), U1.55 (GND), U1.56 (GND), U1.57 (GND), U1.58 (GND), U1.59 (GND), U1.60 (GND), U1.61 (EXP), U1.62 (GND), U1.63 (GND), U1.64 (GND), U1.65 (GND), U1.66 (EXP), U1.67 (EXP), U1.68 (EXP), U1.69 (EXP), U1.70 (EXP), U1.71 (EXP), U1.72 (EXP), U1.73 (EXP), U2.2 (GND), U3.2 (VSS), U4.1 (GND), U4.7 (GND), U5.2 (GND), X1.1, X1.NC1, X1.NC2, X3.A1B12 (GND), X3.B1A12 (GND)
I2C_PWR: R3.5 (2), U1.11 (IO7), U5.3 (EN)
IO34_DBLTAP: C5.1, R17.2, U1.29 (IO34)
MISO: JP1.4, U1.33 (IO37)
MOSI: JP1.5, U1.31 (IO35)
unnamed: CHG.C, R2.1
unnamed: R2.2, U3.1 (STAT)
unnamed: R4.2, U3.5 (PROG)
unnamed: D3.A, R10.2
unnamed: R8.2, X3.A5 (CC1)
unnamed: R5.2, X3.B5 (CC2)
NEOPIX: LED1.1 (DI), U1.28 (IO33)
NEOPIX_PWR: LED1.2 (VDD), U1.25 (IO21)
RESET: C4.1, JP1.16, R1.1, SW2.B (S), SW2.B' (S1), U1.45 (EN)
RX: JP1.3, U1.34 (IO38)
SCK: JP1.6, U1.32 (IO36)
SCL: CONN1.4 (SCL), IC1.C2 (SCL), JP3.11, R3.1, U1.8 (IO4), U4.4 (SCK)
SDA: CONN1.3 (SDA), IC1.C1 (SDA), JP3.12, R3.2 (1), U1.7 (IO3), U4.3 (SDI)
TX: JP1.2, U1.35 (IO39/TCK)
TXD0: JP1.1, U1.39 (TXD0)
VBAT: C3.1, IC1.A3 (VDD), JP3.1, Q3.3 (D), U3.3 (VBAT), X1.2
VBUS: CHG.A, D4.A, JP3.3, Q3.1 (G), R12.2, U3.4 (VDD), X3.A4B9 (VBUS), X3.B4A9 (VBUS)
VHI: C6.1, D4.C, Q3.2 (S), R7.2, U2.1 (IN), U5.1 (IN)
VSENSOR: C11.1, CONN1.2 (V+), R3.3 (1), R3.6 (2), R3.7 (2), R3.8 (2), U4.2 (CSB), U4.5 (SDO), U4.6 (VDDIO), U4.8 (VDD), U5.5 (OUT)

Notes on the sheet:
POWER AND FILTERING
RESET
10K = 100mA
5.0K = 200mA
2.0K = 500mA
1.0K = 1000mA
USB TO SERIAL CONVERTER
LIPO CHARGING
LED
PSRAMCS
NEOPIXEL



Board: 2 copper layers, 50.8 x 22.9 mm, 47 parts (4 on the bottom side), 42 nets.

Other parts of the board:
U$14: PCBFEAT-REV-040
U$15: FEATHERLOGO_MED
U$53: STEMMAQT

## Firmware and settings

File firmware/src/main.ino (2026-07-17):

// vim: foldmethod=marker:foldmarker={{{,}}}
#include <iomanip>
#include <limits>
#include <sstream>

#include <Adafruit_MAX1704X.h>
#include <Adafruit_ThinkInk.h>
#include <NimBLEDevice.h>
#include <esp_sleep.h>

#if defined(GABEN_STARTUP)
#include "gaben.h"
#endif

#define SERVICE_UUID                                                                               \
    NimBLEUUID { "95c7b479-8e84-4ce7-a121-faf74bf48c84" }
#define TOPLINE_UUID                                                                               \
    NimBLEUUID { "d6f4c07e-4a21-4c69-bd15-43a38a871900" }
#define MIDLINE_UUID                                                                               \
    NimBLEUUID { "d6f4c07e-4a21-4c69-bd15-43a38a871901" }
#define BOTLINE_UUID                                                                               \
    NimBLEUUID { "d6f4c07e-4a21-4c69-bd15-43a38a871902" }
#define KEYVAL_UUID                                                                                \
    NimBLEUUID { "d6f4c07e-4a21-4c69-bd15-43a38a871903" }
#define VECTOR_UUID                                                                                \
    NimBLEUUID { "d6f4c07e-4a21-4c69-bd15-43a38a871904" }
#define ARTWORK_UUID                                                                               \
    NimBLEUUID { "d6f4c07e-4a21-4c69-bd15-43a38a871905" }
#define FLUSH_UUID                                                                                 \
    NimBLEUUID { "d6f4c07e-4a21-4c69-bd15-43a38a8719FF" }

#define SPARKBOX_HEIGHT 100
#define SPARKBOX_WIDTH 209

// full-panel artwork framebuffer, 1bpp row-major with MSB-first bytes
// (the same layout Adafruit_GFX::drawBitmap() expects); allocated lazily on
// the first artwork upload because internal DRAM is nearly exhausted by the
// display's own buffers at boot - PSRAM is preferred when the board has it
#define ART_MAX_WIDTH 648
#define ART_MAX_HEIGHT 480
#define ART_BUFFER_SIZE ((ART_MAX_WIDTH / 8) * ART_MAX_HEIGHT)
static uint8_t *ART_BUFFER = nullptr;

static bool artBufferReady()
{
    if (ART_BUFFER != nullptr) {
        return true;
    }
    ART_BUFFER = (uint8_t *)ps_malloc(ART_BUFFER_SIZE);
    if (ART_BUFFER == nullptr) {
        ART_BUFFER = (uint8_t *)malloc(ART_BUFFER_SIZE);
    }
    return ART_BUFFER != nullptr;
}

#define INTERFACE_VERSION "IFv01"

// minimum voltage battery can reach before we go into deep sleep
#define BATT_MINV 2.9

NimBLEServer *BLE_SERVER = nullptr;
std::string BLE_NAME = "INKTF";

Adafruit_MAX17048 maxlipo;
bool MAXLIPO_PRESENT = false;

bool INVERTED = false;
#define FG_COLOR (INVERTED ? EPD_WHITE : EPD_BLACK)
#define BG_COLOR (INVERTED ? EPD_BLACK : EPD_WHITE)

class DualPrint : public Print
{ // {{{
  public:
    DualPrint(Print &a, Print &b)
        : _a(a)
        , _b(b)
    {
    }
    size_t write(uint8_t c) override
    {
        _a.write(c);
        return _b.write(c);
    }
    size_t write(const uint8_t *buffer, size_t size) override
    {
        _a.write(buffer, size);
        return _b.write(buffer, size);
    }

  private:
    Print &_a;
    Print &_b;
}; // }}}
DualPrint Debug(Serial, Serial1);

class CustomDisp : public ThinkInk_583_Mono_AAAMFGN
{ // {{{
  public:
    CustomDisp(int16_t SID, int16_t SCLK, int16_t DC, int16_t RST, int16_t CS, int16_t SRCS,
               int16_t MISO, int16_t BUSY = -1)
        : ThinkInk_583_Mono_AAAMFGN(SID, SCLK, DC, RST, CS, SRCS, MISO, BUSY){};

    CustomDisp(int16_t DC, int16_t RST, int16_t CS, int16_t SRCS, int16_t BUSY = -1,
               SPIClass *spi = &SPI)
        : ThinkInk_583_Mono_AAAMFGN(DC, RST, CS, SRCS, BUSY, spi){};

    // experimenting with adding windowed/partial refresh
    void partialWindow(uint16_t x = 8, uint16_t w = 198, uint16_t y = 92, uint16_t h = 110,
                       bool pt_scan = true)
    {
        uint16_t hrst = x;
        uint16_t hred = x + w;
        uint16_t vrst = y;
        uint16_t vred = y + h;
        uint8_t buf[9] = {0};
        buf[0] = (hrst & 0x300) >> 8; // bits 9:8 of HRST, top 6 bits unused
        buf[1] = hrst & 0xf8;         // bits 7:3 of HRST, bot 3 bits must be 0
        buf[2] = (hred & 0x300) >> 8; // bits 9:8 of HRED, top 6 bits unused
        buf[3] = (hred & 0xf8) | 0x7; // bits 7:3 of HRED, bot 3 bits must be 1
        buf[4] = (vrst & 0x300) >> 8; // bits 9:8 of VRST, top 6 bits unused
        buf[5] = vrst & 0xff;         // bits 7:0 of VRST
        buf[6] = (vred & 0x300) >> 8; // bits 9:8 of VRED, top 6 bits unused
        buf[7] = vred & 0xff;         // bits 7:0 of VRED
        buf[8] = pt_scan ? 1 : 0;     // bottom bit, PT_SCAN flag
        EPD_command(0x90);
        EPD_data(buf, sizeof(buf));
    }
    void partialIn() { EPD_command(0x91); }
    void partialOut() { EPD_command(0x90); }
}; // }}}

// ThinkInk_583_Mono_AAAMFGN MF_DISPLAY(EPD_DC, EPD_RESET, EPD_CS, SRAM_CS, EPD_BUSY);
CustomDisp MF_DISPLAY(EPD_DC, EPD_RESET, EPD_CS, -1 /* SRAM_CS */, EPD_BUSY);

static unsigned long DISP_DEBOUNCE = 0;

struct Point { // {{{
    float x;
    float y;

    Point()
        : x(0)
        , y(0)
    {
    }
    Point(float _x, float _y)
        : x(_x)
        , y(_y)
    {
    }
}; // }}}

struct Points { // {{{
    float yMin;
    float yMax;
    std::vector<Point> points;

    Points()
        : yMin(0)
        , yMax(0)
        , points()
    {
    }

    void clear()
    {
        yMin = 0;
        yMax = 0;
        points.clear();
    }
}; // }}}

struct KeyVal { // {{{
    std::string key;
    std::string val;

    KeyVal()
        : key{""}
        , val{""}
    {
    }
}; // }}}
typedef std::vector<KeyVal> KeyVals;

struct State { // {{{
    bool connected = false;
    std::string topLine{"Starting up..."};
    std::string midLine{"No User"};
    std::string botLine{"No Activity"};
    std::string hostMsg{""};
    std::string battLine{""};

    KeyVals keyvals{9};
    std::vector<Points> sparks{6};

    // when true the display shows the host-provided ART_BUFFER frame
    // instead of the telemetry layout
    bool artMode = false;
    uint16_t artWidth = 0;
    uint16_t artHeight = 0;

    void reset()
    {
        keyvals.clear();
        keyvals.resize(9);
        sparks.clear();
        sparks.resize(6);

        artMode = false;
        artWidth = 0;
        artHeight = 0;

        uint32_t addr = (uint64_t)NimBLEDevice::getAddress() & 0xFFFFFF;
        std::stringstream name;
        name << "INKTF-";
        name << std::uppercase << std::hex << std::setfill('0') << std::setw(6) << addr;
        BLE_NAME = name.str();

        connected = false;
        topLine = "Waiting on connection...";
        midLine = BLE_NAME;
        botLine = "";
        hostMsg = "";
        keyvals[0].key = "OS";
        keyvals[0].val = "--";
        keyvals[1].key = "BIOS";
        keyvals[1].val = "--";
        keyvals[2].key = "STEAM";
        keyvals[2].val = "--";
        keyvals[3].key = "CPU";
        keyvals[3].val = "-- dC";
        keyvals[4].key = "GPU";
        keyvals[4].val = "-- dC";
        keyvals[5].key = "FAN";
        keyvals[5].val = "-- RPM";
        keyvals[6].key = "CPU";
        keyvals[6].val = "--%";
        keyvals[7].key = "GPU";
        keyvals[7].val = "--%";
        keyvals[8].key = "MEM";
        keyvals[8].val = "--%";
    }
} STATE; // }}}

void drawStatic();
void drawArt();

class ServerCallbacks : public NimBLEServerCallbacks
{ // {{{
    void onConnect(NimBLEServer *server, NimBLEConnInfo &conn) override
    {
        Debug.println("got connection");
        // we don't want any other devices to see us once we are connected
        // to a host
        NimBLEDevice::stopAdvertising();
        STATE.connected = true;
    }

    void onDisconnect(NimBLEServer *server, NimBLEConnInfo &conn, int reason) override
    {
        Debug.print("got disconnect event, connected count: ");
        Debug.println(server->getConnectedCount());
        // connected count appears to be updated after this callback is
        // triggered, so the count will be at least 1 higher than reality
        if (server->getConnectedCount() <= 1) {
            if (STATE.connected) {
                DISP_DEBOUNCE = 100;
            }
            STATE.reset();
        }
        NimBLEDevice::startAdvertising();
    }
} SERVER_CALLBACKS; // }}}

class StatusLineCallbacks : public NimBLECharacteristicCallbacks
{ // {{{
    void onWrite(NimBLECharacteristic *characteristic, NimBLEConnInfo &conn) override
    {
        std::string value = characteristic->getValue();
        auto uuid = characteristic->getUUID();
        if (uuid == TOPLINE_UUID && STATE.topLine != value) {
            STATE.topLine = value;
        } else if (uuid == MIDLINE_UUID && STATE.midLine != value) {
            STATE.midLine = value;
        } else if (uuid == BOTLINE_UUID && STATE.botLine != value) {
            STATE.botLine = value;
        } else if (uuid != TOPLINE_UUID && uuid != MIDLINE_UUID && uuid != BOTLINE_UUID) {
            Debug.print("Got value (");
            Debug.print(value.c_str());
            Debug.print(") for unknown UUID (");
            Debug.print(uuid.toString().c_str());
            Debug.println("), ignoring.");
            return;
        }
    }
} STATUS_CALLBACKS; // }}}

class KeyValCallbacks : public NimBLECharacteristicCallbacks
{ // {{{
    typedef struct __attribute__((packed)) {
        uint8_t index;
        char key[32];
        char val[32];
    } Msg;

    void onWrite(NimBLECharacteristic *characteristic, NimBLEConnInfo &conn) override
    {
        std::string value = characteristic->getValue();
        Msg msg;
        if (value.length() == sizeof(Msg)) {
            memcpy(&msg, value.data(), sizeof(Msg));
            STATE.keyvals[msg.index].key = msg.key;
            STATE.keyvals[msg.index].val = msg.val;
        } else {
            Debug.print("got bad keyval write, size: ");
            Debug.println(value.length());
        }
    }
} KEYVAL_CALLBACKS; // }}}

class VectorCallbacks : public NimBLECharacteristicCallbacks
{ // {{{
    typedef struct __attribute__((packed)) {
        uint8_t index;
        uint8_t count;
        float minVal;
        float maxVal;
        uint8_t values[32 * 2]; // 32 (x, y) pairs, 64 bytes
        // total 74 bytes
    } Msg;

    void onWrite(NimBLECharacteristic *characteristic, NimBLEConnInfo &conn) override
    {
        std::string value = characteristic->getValue();
        Msg msg;
        if (value.length() >= 2) {
            memcpy(&msg, value.data(), sizeof(Msg));
            Debug.print("got vector for index (");
            Debug.print(msg.index);
            Debug.print(") with ");
            Debug.print(msg.count);
            Debug.print(" values, min ");
            Debug.print(msg.minVal);
            Debug.print(", max ");
            Debug.println(msg.maxVal);
            STATE.sparks[msg.index].clear();
            STATE.sparks[msg.index].yMin = msg.minVal;
            STATE.sparks[msg.index].yMax = msg.maxVal;
            for (int i = 0; i < msg.count; i += 2) {
                STATE.sparks[msg.index].points.emplace_back(msg.values[i] / 255.0,
                                                            msg.values[i + 1] / 255.0);
            }
        } else {
            Debug.print("got bad vectors write, size: ");
            Debug.println(value.length());
        }
    }
} VECTOR_CALLBACKS; // }}}

class ArtworkCallbacks : public NimBLECharacteristicCallbacks
{ // {{{
    // opcodes for the artwork transfer protocol, all multi-byte ints are LE:
    //   0x00 BEGIN: uint16 width, uint16 height; resets the frame
    //   0x01 DATA:  uint32 byte offset, then raw 1bpp payload bytes
    //   0x02 SHOW:  switch the display to the uploaded frame
    //   0x03 CLEAR: return the display to the telemetry layout
    void onWrite(NimBLECharacteristic *characteristic, NimBLEConnInfo &conn) override
    {
        std::string value = characteristic->getValue();
        if (value.empty()) {
            return;
        }
        const uint8_t *data = (const uint8_t *)value.data();
        switch (data[0]) {
        case 0x00: {
            if (value.length() < 5) {
                Debug.println("got short artwork begin message");
                return;
            }
            uint16_t w = data[1] | (data[2] << 8);
            uint16_t h = data[3] | (data[4] << 8);
            if (w > ART_MAX_WIDTH || h > ART_MAX_HEIGHT) {
                Debug.println("rejecting oversized artwork frame");
                return;
            }
            if (!artBufferReady()) {
                Debug.println("no memory for artwork frame, rejecting upload");
                return;
            }
            STATE.artWidth = w;
            STATE.artHeight = h;
            memset(ART_BUFFER, 0, ART_BUFFER_SIZE);
            break;
        }
        case 0x01: {
            if (value.length() < 6) {
                Debug.println("got short artwork data message");
                return;
            }
            uint32_t offset = data[1] | (data[2] << 8) | (data[3] << 16) | ((uint32_t)data[4] << 24);
            size_t len = value.length() - 5;
            if (ART_BUFFER == nullptr) {
                Debug.println("ignoring artwork data before a begin message");
                return;
            }
            if (offset + len > ART_BUFFER_SIZE) {
                Debug.println("rejecting artwork data past end of buffer");
                return;
            }
            memcpy(ART_BUFFER + offset, data + 5, len);
            break;
        }
        case 0x02: {
            if (STATE.artWidth == 0 || STATE.artHeight == 0) {
                Debug.println("ignoring artwork show, no frame uploaded");
                return;
            }
            Debug.println("showing artwork frame");
            STATE.artMode = true;
            DISP_DEBOUNCE = 100;
            break;
        }
        case 0x03: {
            Debug.println("leaving artwork mode");
            STATE.artMode = false;
            DISP_DEBOUNCE = 100;
            break;
        }
        default: {
            Debug.print("got unknown artwork opcode: ");
            Debug.println(data[0]);
            break;
        }
        }
    }
} ARTWORK_CALLBACKS; // }}}

class FlushCallbacks : public NimBLECharacteristicCallbacks
{ // {{{
    void onWrite(NimBLECharacteristic *characteristic, NimBLEConnInfo &conn) override
    {
        STATE.hostMsg = characteristic->getValue();
        DISP_DEBOUNCE = 100;
    }
} FLUSH_CALLBACKS; // }}}

void setup()
{ // {{{
    Serial.begin(115200);
    Serial1.begin(115200);
    // these usb serial and rx/tx interfaces are combined in the Debug instance
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
void loop()
{ // {{{
    static unsigned long LAST_MS = 0;
    static unsigned long CONN_DEBOUNCE = 5000;
    static unsigned long BATT_DEBOUNCE = 1000;
    static float last_battp = 0;
    static float last_battv = 0;

    auto now = millis();
    auto delta = now - LAST_MS;
    if (now < LAST_MS) {
        // handling rollover
        Debug.println("handling time rollover");
        delta = (std::numeric_limits<unsigned long>::max() - LAST_MS) + now;
    }

    if (CONN_DEBOUNCE > 0 && CONN_DEBOUNCE > delta) {
        CONN_DEBOUNCE -= delta;
    } else if (CONN_DEBOUNCE > 0) {
        // NOTE: this should be handled in our SERVER_CALLBACKS but we don't
        //       always seem to get the onDisconnect() callback and get stuck
        //       with advertising stopped, so might as well just check here...
        bool advertising = NimBLEDevice::getAdvertising()->isAdvertising();
        uint8_t connections = BLE_SERVER->getConnectedCount();
        if (!advertising && connections == 0) {
            Debug.print("starting advertisement, we have no connections");
            NimBLEDevice::startAdvertising();
        } else if (advertising && connections > 0) {
            Debug.print("stopping advertisement, we have connections");
            NimBLEDevice::stopAdvertising();
        }
        CONN_DEBOUNCE = 5000;
    }

    if (MAXLIPO_PRESENT && BATT_DEBOUNCE > 0 && BATT_DEBOUNCE > delta) {
        BATT_DEBOUNCE -= delta;
    } else if (MAXLIPO_PRESENT && BATT_DEBOUNCE > 0) {
        float battp = maxlipo.cellPercent();
        float battv = maxlipo.cellVoltage();
        if (abs(battp - last_battp) > 1 || abs(battv - last_battv) > 0.01) {
            last_battp = battp;
            last_battv = battv;
            Debug.print("batt: ");
            Debug.print(battp, 1);
            Debug.print("% total, ");
            Debug.print(maxlipo.chargeRate(), 1);
            Debug.print("% rate, ");
            Debug.print(battv, 2);
            Debug.println(" V");
            std::stringstream line;
            line << std::fixed << std::setprecision(2) << battv << " V";
            STATE.battLine = line.str();
            DISP_DEBOUNCE = 10;
        }
        BATT_DEBOUNCE = 1000;
    }

    // without a fuel gauge last_battv stays 0 forever, which must not be
    // mistaken for a drained battery
    if (MAXLIPO_PRESENT && last_battv < BATT_MINV) {
        Debug.println("drawing low battery message");
        DISP_DEBOUNCE = 0;
        MF_DISPLAY.begin(THINKINK_MONO);
        MF_DISPLAY.clearBuffer();
        MF_DISPLAY.fillScreen(BG_COLOR);
        drawLowBatt();
        MF_DISPLAY.display();
        MF_DISPLAY.powerDown();
        Debug.println("going into deep sleep");
        // esp_sleep_enable_timer_wakeup(10 * 1000000ULL);
        esp_deep_sleep_start();
        goto loop_end;
    }

    if (DISP_DEBOUNCE > 0 && DISP_DEBOUNCE > delta) {
        DISP_DEBOUNCE -= delta;
    } else if (DISP_DEBOUNCE > 0) {
        Debug.println("drawing to display");
        DISP_DEBOUNCE = 0;
        MF_DISPLAY.begin(THINKINK_MONO);
        MF_DISPLAY.clearBuffer();
        MF_DISPLAY.fillScreen(BG_COLOR);
        if (STATE.artMode) {
            drawArt();
        } else {
            drawStatic();
        }
        MF_DISPLAY.display();
        MF_DISPLAY.powerDown();
        Debug.println("drew to display");
    }

    // Debug.println("entering light sleep");
    // esp_sleep_enable_timer_wakeup(10 * 1000ULL);
    // esp_err_t err = esp_light_sleep_start();
    // Debug.println("woke from light sleep");
    // Debug.print("After sleep, err=%s\n", esp_err_to_name(err));
    // Debug.print("Wake reason=%d\n", esp_sleep_get_wakeup_cause());
    // delay(1);

loop_end:
    LAST_MS = now;
    delay(10);
} // }}}

void drawText(const char *text, const int16_t &x = -1, const int16_t &y = -1,
              const uint8_t &size = 1, const bool &wrap = false)
{ // {{{
    if (x >= 0 && y >= 0) {
        MF_DISPLAY.setCursor(x, y);
    }
    MF_DISPLAY.setTextSize(size);
    MF_DISPLAY.setTextColor(FG_COLOR);
    MF_DISPLAY.setTextWrap(wrap);
    MF_DISPLAY.print(text);
} // }}}

void drawLogo(int16_t &x, const int16_t &y = 0)
{ // {{{
    MF_DISPLAY.fillRoundRect(x, y, 101, 101, 3, FG_COLOR);
    MF_DISPLAY.fillCircle(x + 50, y + 50, 31, BG_COLOR);
    MF_DISPLAY.fillCircle(x + 50, y + 50, 23, FG_COLOR);
    x += 101;
} // }}}

void drawSparkbox(int16_t &x, const int16_t &y, std::string &title, const std::string &value,
                  const Points &points)
{ // {{{
    const int16_t w = SPARKBOX_WIDTH;
    const int16_t h = SPARKBOX_HEIGHT;
    const int16_t hpad = 8;
    const int16_t vpad = 6;
    const int16_t title_h = 26;
    const int16_t graph_h = (h - title_h) - 32;
    const int16_t graph_w = w - 20;
    const int16_t graph_x = x + 10;
    const int16_t graph_y = (y + h) - 16;

    if (!title.empty()) {
        MF_DISPLAY.drawRoundRect(x, y, w, h, 4, FG_COLOR);
        MF_DISPLAY.drawRoundRect(x + 1, y + 1, w - 2, h - 2, 4, FG_COLOR);
        MF_DISPLAY.fillRect(x, y + title_h, w, 1, FG_COLOR);
        drawText(title.c_str(), x + hpad, y + vpad, 2);
        drawText(value.c_str(), (x + (w - hpad)) - (12 * strlen(value.c_str())), y + vpad, 2);

        std::stringstream maxstrm;
        maxstrm << std::fixed << std::setprecision(0) << points.yMax;
        auto maxstr = maxstrm.str();
        drawText(maxstr.c_str(), x + hpad, y + title_h + vpad);

        std::stringstream minstrm;
        minstrm << std::fixed << std::setprecision(0) << points.yMin;
        auto minstr = minstrm.str();
        drawText(minstr.c_str(), x + hpad, y + h - (vpad + 7));

        if (points.points.size() >= 2) {
            int16_t s_x = 0.0, s_y = 0.0, e_x = 0.0, e_y = 0.0;
            for (auto p = points.points.cbegin(); p != points.points.cend() - 1; ++p) {
                s_x = graph_x + (p->x * graph_w);
                e_x = graph_x + ((p + 1)->x * graph_w);
                s_y = graph_y + (p->y * graph_h * -1.0);
                e_y = graph_y + ((p + 1)->y * graph_h * -1.0);
                MF_DISPLAY.drawLine(s_x, s_y, e_x, e_y, FG_COLOR);
                MF_DISPLAY.drawLine(s_x, s_y - 1, e_x, e_y - 1, FG_COLOR);
                MF_DISPLAY.drawLine(s_x, s_y + 1, e_x, e_y + 1, FG_COLOR);
                MF_DISPLAY.drawLine(s_x - 1, s_y, e_x - 1, e_y, FG_COLOR);
                MF_DISPLAY.drawLine(s_x + 1, s_y, e_x + 1, e_y, FG_COLOR);
            }
        }
    }

    x += w;
} // }}}

void drawDiscreteBox(int16_t &x, const int16_t &y, const std::string &title,
                     const std::string &value)
{ // {{{
    const int16_t w = 209;
    const int16_t h = 26;
    const int16_t hpad = 8;
    const int16_t vpad = 6;

    if (!title.empty()) {
        MF_DISPLAY.drawRoundRect(x, y, w, h, 4, FG_COLOR);
        MF_DISPLAY.drawRoundRect(x + 1, y + 1, w - 2, h - 2, 4, FG_COLOR);
        drawText(title.c_str(), x + hpad, y + vpad, 2);
        drawText(value.c_str(), (x + (w - hpad)) - (12 * strlen(value.c_str())), y + vpad, 2);
    }

    x += w;
} // }}}
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

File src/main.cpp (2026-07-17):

#include <cstdlib>

#include <QApplication>
#include <QCommandLineParser>
#include <QGuiApplication>
#include <QDebug>
#include <QDir>
#include <QFont>
#include <QFontDatabase>
#include <QIcon>
#include <QLoggingCategory>
#include <QQmlApplicationEngine>
#include <QQmlContext>
#include <QQuickStyle>
#include <QQuickWindow>
#include <QSettings>
#include <QTimer>

#include "config.h"
#include "loghandler.hpp"
#include "panel-finder.hpp"
#include "panel-state.hpp"
#include "panel.hpp"
#include "svcmgr.hpp"
#include "unsig.hpp"

#define EXIT_SUCCESS 0

using namespace Qt::Literals::StringLiterals;

bool registerFonts()
{
    bool success = true;
    QString prefix = u":/%1/resources/IBM_Plex_Mono/"_s.arg(QML_URI);
    const auto entries = QDir(prefix).entryList({u"*.ttf"_s});
    for (const QString &f : entries) {
        if (QFontDatabase::addApplicationFont(prefix + f) == -1) {
            success = false;
            break;
        }
    }
    return success;
}

int runUi(int argc, char *argv[])
{
    qDebug() << "Running with UI...";
    QApplication app(argc, argv);
    app.setApplicationName(PROJECT_DISPLAY_NAME);
    app.setOrganizationName(ORG_NAME);
    app.setOrganizationDomain(ORG_DOMAIN);
    app.setApplicationVersion(PROJECT_GITREV);
    app.setWindowIcon(QIcon(u":/%1/resources/icon.png"_s.arg(QML_URI)));
    QSettings settings;
    qDebug() << "Settings stored in:" << settings.fileName();

    QQuickStyle::setStyle("Basic");
    if (!registerFonts()) {
        qWarning() << "Failed to register custom fonts!";
    } else {
        QFont font(u"IBM Plex Mono"_s, -1, QFont::Medium);
        // NOTE: we use pixel size rather than point size here so our layout
        //       elements in QML are consistent across platforms
        font.setPixelSize(24);
        app.setFont(font);
    }

    QQmlApplicationEngine engine(&app);
    QQmlContext *ctx = engine.rootContext();

    PanelFinder *panelFinder = new PanelFinder(&app);
    ctx->setContextProperty("panelFinder", panelFinder);

    SvcMgr *svcMgr = new SvcMgr(&app);
    ctx->setContextProperty("svcMgr", svcMgr);

    PanelState *fs = new PanelState(&app);
    ctx->setContextProperty("panelState", fs);

    const QUrl url(u"qrc:/%1/qml/main.qml"_s.arg(QML_URI));
    QObject::connect(
        &engine, &QQmlApplicationEngine::objectCreated, &app,
        [url, &app](QObject *obj, const QUrl &objUrl) {
            if (!obj && url == objUrl) {
                qCritical("Failed to load any QML objects!");
                app.quit();
            }
        },
        Qt::QueuedConnection);
    engine.load(url);

    return app.exec();
}

int runHeadless(int argc, char *argv[])
{
    qDebug() << "Running headless...";
    // artwork frames are composed with QPainter and fonts, which needs a
    // gui application; the offscreen platform keeps it display-free so the
    // service still runs fine from a systemd unit
    qputenv("QT_QPA_PLATFORM", "offscreen");
    QGuiApplication app(argc, argv);
    UnSig unsig(&app);
    unsig.catchSignal(SIGINT);
    unsig.catchSignal(SIGTERM);

    app.setApplicationName(PROJECT_DISPLAY_NAME);
    app.setOrganizationName(ORG_NAME);
    app.setOrganizationDomain(ORG_DOMAIN);
    app.setApplicationVersion(PROJECT_GITREV);
    if (!registerFonts()) {
        qWarning() << "Failed to register custom fonts!";
    }

    Panel panel(&app);

    int exitCode = EXIT_SUCCESS;

    QObject::connect(&app, &QCoreApplication::aboutToQuit, &panel, &Panel::stop);
    QObject::connect(&unsig, &UnSig::unixSignal, &panel, &Panel::stop);
    exitCode = app.exec();
    return exitCode;
}

int installService([[maybe_unused]] int argc, [[maybe_unused]] char *argv[])
{
    SvcMgr svcMgr;
    svcMgr.installService();
    return EXIT_SUCCESS;
}

int main([[maybe_unused]] int argc, [[maybe_unused]] char *argv[])
{
    LogHandler::install(PROJECT_NAME ".log", 50);

    QLoggingCategory::setFilterRules("qt.bluetooth* = false");
    qDebug() << PROJECT_DISPLAY_NAME << "version" << PROJECT_GITREV;

    QCommandLineParser parser;
    parser.setSingleDashWordOptionMode(QCommandLineParser::ParseAsLongOptions);
    parser.setApplicationDescription(u"%1 data feed generator."_s.arg(PROJECT_NAME));
    parser.addHelpOption();
    parser.addVersionOption();

    QCommandLineOption installOption{u"install"_s, u"Install as a systemd service."_s};
    parser.addOption(installOption);

    QCommandLineOption headlessOption{u"headless"_s, u"Run without UI, used for service mode."_s};
    parser.addOption(headlessOption);

    QStringList args;
    for (int i = 0; i < argc; ++i) {
        args << QString(argv[i]);
    }
    parser.process(args);

    if (parser.isSet(installOption)) {
        return installService(argc, argv);
    } else if (parser.isSet(headlessOption)) {
        return runHeadless(argc, argv);
    } else {
        return runUi(argc, argv);
    }
}

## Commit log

2025-09-25 Begin adding firmware.
    [partitions.csv]
2025-09-26 Swap to arduino and adafruit libs for quick first prototype.
    [partitions.csv]
2025-10-01 Fix characteristic callbacks, use BLE addr for name.
    [main.ino]
2025-10-01 Specify paritions explicitly to disable UF2 usbdrive boot.
    [partitions.csv]
2025-10-02 Load current steam user.
2025-10-02 Fix missing double quote.
    [main.ino]
2025-10-07 Fix current user on other plats, capture app start/stop.
2025-10-07 Fix msg queue interactions.
    [main.cpp]
2025-10-10 Handle case where app is bundled into appimage.
2026-03-23 Actually use name filtering.
2026-05-01 Rework pages to use settings, swap between list and config.
    [main.cpp]
2026-05-11 Add ability to invert colors.
    Looks kinda awful in some states, but we can tweak it.
    [main.ino]
2026-05-11 Steam instance should track running app details.
2026-05-12 Fix some clazy analysis warnings.
    [main.cpp]
2026-05-29 Bring in board files eink breakout and feather friend.
    [Adafruit eInk Breakout Friend.brd, Adafruit eInk Breakout Friend.kicad_pcb, Adafruit eInk Breakout Friend.kicad_sch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]
2026-05-30 Map the rest of the component models to the breakout board.
    [Adafruit eInk Breakout Friend.kicad_pcb]
2026-05-30 Use TE 2-2492111-4 model for FPC connector, is actually JUSHUO AFC07-S24ECA-00.
    JUSHUO part doesn't have an easily available model, but it does appear
    to be a nearly identical clone of the TE part, available on LCSC. This
    model matches all critical dimensions.
    [Adafruit eInk Breakout Friend.kicad_pcb]
2026-05-30 Bring in feather board and begin placing component CAD.
    [Adafruit ESP32-S3 8MB No PSRAM.brd, Adafruit ESP32-S3 8MB No PSRAM.kicad_pcb, Adafruit ESP32-S3 8MB No PSRAM.kicad_sch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]
2026-06-09 Add support for breakout epd board.
2026-06-11 Try putting esp32 into light sleep.
    Need to enable some more system configuration that I'm not entirely sure
    works with the Arduino framework. I'd rather switch to ESP-IDF but I
    also don't want to alienate folks who aren't familiar with it since so
    many people are familiar with Arduino.
2026-06-11 Add some images of the boards from kicad.
2026-06-12 Add CAD for 3D printed enclosure.
    [Inkterface - Battery Retainer.step, Inkterface - Board Plate.step, Inkterface - Faceplate.step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]
2026-06-12 Add some links and an assembly guide.
2026-06-12 Add an assembly tutorial video.
2026-06-13 Include pin names in wiring diagram.
2026-06-16 Display battery state, only update when it actually changes.
2026-06-18 Show charge reminder when battery is low. Print debug to RX/TX pins.
2026-06-24 Add assembly guide pages to design mockup.
2026-06-24 Add STL's for folks that can't easily use STEP files.
    [Inkterface - Battery Retainer.stl, Inkterface - Board Plate.stl, Inkterface - Faceplate.stl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]
2026-06-25 Add assembly pdf.
2026-06-25 Adjust assembly guide.
2026-06-25 Fix bug where we sometimes get stuck advertising/not advertising.
    Not sure why these callbacks seem to fail, and this actually might not
    handle the loss of connection still, but we can also track last comms
    for this too.
    [main.ino]
2026-07-04 Add a link to an option for the battery.
2026-07-14 Add details and support for Feather V2 as well as V1.
    Mistakenly linked the wrong board before, but for folks who bought them
    it's not really a big deal, and we can support them with just a pinout
    change and we can disable the MAX battery feedback. Still need to add
    support for the feedback mechanism on the V2 board, but also would be
    nice to support other boards too.
    [Adafruit ESP32 Feather V2.brd, Adafruit ESP32 Feather V2.kicad_pcb, Adafruit ESP32 Feather V2.kicad_sch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]
2026-07-15 Fix truncated pin names, fix featherv2 env board name.
2026-07-15 Make readme exactly match the assembly documentation.
2026-07-17 Add now-playing artwork mode with playtime and achievements
    Firmware gains an artwork characteristic that accepts a chunked 1bpp
    648x480 frame (BEGIN/DATA/SHOW/CLEAR opcodes) and blits it in place of
    the telemetry layout. The app composes a frame from the running game's
    box art (local librarycache first, storefront CDN as fallback), total
    playtime from localconfig.vdf, and achievement progress from the keyless
    Steam Community endpoint, dithers it for e-ink, and streams it to the
    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
2026-07-17 Add CI release builds, browser flasher, and one-line installer
    A tag push now builds the AppImage (Ubuntu 22.04 + Qt 6.9 to match the
    upstream Containerfile) and merged firmware images for both Feather
    variants, attaches them to a GitHub release, and deploys an ESP Web
    Tools page to GitHub Pages so the firmware can be flashed from Chrome
    or Edge with no local toolchain. scripts/install.sh lets Steam Machine
    users install the latest app release with a single curl command.
2026-07-17 Rework readme for the fork: credit, features, quick install
    Keeps all upstream documentation intact below a new section crediting
    the original Valve project and describing what this fork adds along
    with the simplified install paths.
2026-07-17 Link the assembly video from upstream instead of bundling it
    The 105MB video exceeds GitHub file size limits, so this fork keeps it
    out of history and points at the original GitLab copy.
2026-07-17 Fix boot crash and phantom low-battery sleep found in hardware testing
    The artwork framebuffer was a 38KB static allocation, which pushed the
    classic ESP32 past its internal DRAM budget: the display driver mallocs
    two 38KB buffers of its own at global construction, the second of which
    started failing and crashed the first draw with a null buffer. The
    artwork buffer is now allocated lazily on the first upload, preferring
    PSRAM, so boot memory matches upstream exactly and boards without the
    extra memory simply reject artwork uploads instead of crashing.
    Also guards the low-battery deep sleep on MAXLIPO_PRESENT; on boards
    without the fuel gauge the voltage reads as zero forever and the panel
    w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
    [main.ino]
2026-07-17 Strip UTF-8 BOMs that leaked in from a Windows edit
    The BOM made piping install.sh to sh print a harmless but confusing shebang warning before running normally.
2026-07-17 Bundle the offscreen platform plugin in the AppImage
    The headless service now runs on the offscreen QPA platform to compose artwork frames, but the appimage deploy step only bundles the platform plugin the desktop app links (xcb), so the service died on startup with a missing-plugin error. Copy libqoffscreen.so in beside it.
2026-07-17 Use a fixed 244-byte chunk size for artwork transfers
    Qt's BlueZ backend reports the 23-byte minimum MTU even though the link negotiates 256, which stretched a frame transfer to minutes. The firmware always negotiates 256 and BlueZ handles oversized writes with the long-write procedure regardless, so a fixed chunk is safe and cuts the transfer to about ten seconds.

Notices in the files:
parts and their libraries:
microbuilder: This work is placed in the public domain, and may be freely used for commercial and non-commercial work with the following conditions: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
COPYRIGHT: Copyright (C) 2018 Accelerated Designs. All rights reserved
